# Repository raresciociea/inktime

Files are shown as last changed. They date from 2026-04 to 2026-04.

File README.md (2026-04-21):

# InkTime — Open Source E-Paper Smartwatch

> Cheap, open-source smartwatch built around the Nordic nRF52840 SoC and an e-paper display.

---

## Block Diagram

```text
                          ┌─────────────────────────────────────────────┐
                          │              nRF52840 (U$1)                  │
                          │                                              │
         ┌────────────┐   │  SPI (P0.02/P0.03/P0.05/P0.15/P0.16/P0.17) │
         │  E-Paper   │◄──┤  EPD power ctrl (P1.01)                    │
         │  Display   │   │                                              │
         │  (J2 FPC)  │   │  I2C (P0.06 SDA / P0.07 SCL)               │
         └────────────┘   │   ├─► BQ25180  (IC1)  Battery Charger       │
                          │   ├─► BMA423   (IC2)  Accelerometer/IMU     │
         ┌────────────┐   │   ├─► DRV2605  (IC3)  Haptic Driver         │
         │  Battery   │──►│   └─► MAX17048 (U1)   Fuel Gauge            │
         │  (LiPo)    │   │                                              │
         └────────────┘   │  GPIO                                        │
                          │   ├─► HAPTIC_EN  (P0.12)                    │
         ┌────────────┐   │   ├─► IMU_INT1   (P0.08)                    │
         │  Buttons   │──►│   ├─► IMU_INT2   (P1.08)                    │
         │  UP/ENT/DN │   │   ├─► PMIC_INT   (P0.11)                    │
         └────────────┘   │   ├─► SW_UP      (P0.13)                    │
                          │   ├─► SW_ENT     (P0.14)                    │
         ┌────────────┐   │   └─► SW_DN      (P1.02)                    │
         │ RT6160AWSC │◄──┤  I2C (shared bus)                           │
         │ Buck-Boost │   │                                              │
         │   (IC9)    │   │  SWD debug (SWDIO / SWDCLK / SWO)          │
         └────────────┘   │  32MHz XTAL (X1)  /  32.768kHz XTAL (X2)  │
                          │  2.4GHz Antenna (ANT1)                      │
         ┌────────────┐   └─────────────────────────────────────────────┘
         │  USB-C     │
         │  (J3)      │──► BQ25180 (charging)
         └────────────┘──► USBLC6-2SC6Y (ESD protection, D1)
```

---

## Bill of Materials (BOM)

| Ref | Qty | Component | Description | Package | JLC Parts Link | Datasheet |
|-----|-----|---|---|---|---|---|
| U$1 | 1 | nRF52840-QIAA | Main MCU — BLE 5.0 + ARM Cortex-M4F | AQFN-73 (7×7mm) | [JLC C190794](https://jlcpcb.com/partdetail/NordicSemiconductor-nRF52840_QIAA/C190794) | [Datasheet](https://infocenter.nordicsemi.com/pdf/nRF52840_PS_v1.5.pdf) |
| IC1 | 1 | BQ25180YBGR | 1-cell LiPo charger, I2C, 1A | 8-DSBGA (1.6×1.1mm) | [JLC Parts Search](https://jlcpcb.com/parts/componentSearch?searchTxt=BQ25180) | [Datasheet](https://www.ti.com/lit/ds/symlink/bq25180.pdf) |
| IC2 | 1 | BMA423 | Triaxial accelerometer + step counter, I2C/SPI | LGA-12 (2×2mm) | [JLC Parts Search](https://jlcpcb.com/parts/componentSearch?searchTxt=BMA423) | [Datasheet](https://www.bosch-sensortec.com/media/boschsensortec/downloads/datasheets/bst-bma423-ds000.pdf) |
| IC3 | 1 | DRV2605YZFR | Haptic driver for ERM/LRA motors, I2C | 9-BGA (1.44×1.44mm) | [JLC Parts Search](https://jlcpcb.com/parts/componentSearch?searchTxt=DRV2605YZFR) | [Datasheet](https://www.ti.com/lit/ds/symlink/drv2605.pdf) |
| U1 | 1 | MAX17048G+T10 | 1-cell fuel gauge, ModelGauge, I2C | TDFN-8 (2×2mm) | [JLC Parts Search](https://jlcpcb.com/parts/componentSearch?searchTxt=MAX17048G) | [Datasheet](https://datasheets.maximintegrated.com/en/ds/MAX17048-MAX17049.pdf) |
| IC9 | 1 | RT6160AWSC | Buck-boost DC/DC regulator, I2C | 15-WL-CSP (1.4×2.3mm) | [JLC Parts Search](https://jlcpcb.com/parts/componentSearch?searchTxt=RT6160AWSC) | [Datasheet](https://www.richtek.com/assets/product_file/RT6160A/DS6160A-00.pdf) |
| ANT1 | 1 | 2450AT18B100E | 2.45 GHz chip antenna | 3216 SMD | [JLC Parts Search](https://jlcpcb.com/parts/componentSearch?searchTxt=2450AT18B100E) | [Datasheet](https://www.johansontechnology.com/datasheets/2450AT18B100E.pdf) |
| J2 | 1 | Molex 503480-2400 | 0.5mm FPC connector, 24-pin, right-angle | SMD | [JLC Parts Search](https://jlcpcb.com/parts/componentSearch?searchTxt=503480-2400) | [Datasheet](https://www.molex.com/en-us/products/part-detail/5034802400) |
| J3 | 1 | KH-TYPE-C-16P | USB-C 16-pin receptacle | SMD | [JLC C2765186](https://jlcpcb.com/partdetail/Kinghelm-KH_TYPE_C_16P/C2765186) | [Datasheet](https://www.kinghelm.net/product/kh-type-c-16p.html) |
| J1 | 1 | TC2030-IDC | Tag-Connect 6-pin SWD debug connector | PTH | [Tag-Connect (External)](https://www.tag-connect.com/product/tc2030-idc) | [Datasheet](https://www.tag-connect.com/wp-content/uploads/bsk-pdf-manager/TC2030-IDC_1.pdf) |
| X1 | 1 | 32 MHz Crystal | Main RF crystal | 2016 SMD | JLC Parts | Nordic ref design |
| X2 | 1 | 32.768 kHz Crystal | RTC crystal | 3215 SMD | JLC Parts | Nordic ref design |
| L1 | 1 | Wurth 744043680 (68 µH) | EPD boost inductor | 4828 SMD | [JLC C408334](https://jlcpcb.com/partdetail/WurthElektronik-744043680/C408334) | [Datasheet](https://www.we-online.com/catalog/datasheet/744043680.pdf) |
| L2 | 1 | 10 µH inductor | DC-DC inductor for nRF DCC pin | 0201 | JLC Parts | — |
| L3 | 1 | 15 nH inductor | RF impedance matching network | 0201 | JLC Parts | — |
| L7 | 1 | FTC252012SR47MBCA (0.47 µH) | Buck-boost inductor | 2016 SMD | [JLC C5832368](https://jlcpcb.com/partdetail/6763488-FTC252012SR47MBCA/C5832368) | [Datasheet](https://product.tdk.com/en/search/inductor/inductor/smd/info?part_no=FTC252012SR47MBCA) |
| D1 | 1 | USBLC6-2SC6Y | USB ESD protection TVS diode array | SOT-23-6 | JLC Parts | [Datasheet](https://www.st.com/resource/en/datasheet/usblc6-2sc6y.pdf) |
| D2, D4, D5 | 3 | MBR0530 | Schottky diode 30V/0.5A | SOD-123 | JLC Parts | [Datasheet](https://www.onsemi.com/pdf/datasheet/mbr0530t1-d.pdf) |
| Q1 | 1 | P-channel MOSFET | EPD 3.3V power switch | SOT-23 | JLC Parts | — |
| Q3 | 1 | SI1308EDL-T1-GE3 | N-channel MOSFET 30V/1.5A, EPD gate driver | SC-70 | JLC Parts | [Datasheet](https://www.vishay.com/docs/63401/si1308edl.pdf) |
| SW_UP, SW_ENT, SW_DN | 3 | EVP-AKE31A | Tactile push button, SMD | SMD | JLC Parts | [Datasheet](https://industrial.panasonic.com/ww/products/pt/light-touch-switches/models/EVPAKE31A) |
| R1–R18, various | ~20 | Resistors | Various values (10K, 5K1, 3K3, 7.68K, 2.2Ω, 0.47Ω) | 0201 | JLC Parts | — |
| C1–C43, EPD_Cx | ~60 | Capacitors | 1pF – 22µF decoupling/filtering | 0201 (≤100nF), 0402 (>100nF) | JLC Parts | — |
| TP_* | 14 | Test pads | GND, 3V3, VBAT, SDA, SCL, SWDIO, SWDCLK, SWO, RESET, etc. | TP20R | — | — |
| SJ1 | 1 | Solder jumper | Configuration jumper | — | — | — |

---

## Hardware Functionality

### Microcontroller — nRF52840
The nRF52840 is an ARM Cortex-M4F SoC from Nordic Semiconductor operating at 64 MHz with 1 MB Flash and 256 KB RAM. It integrates a Bluetooth 5.0 radio (BLE + 802.15.4), hardware AES/ECB/CCM/AAR, and a USB 2.0 full-speed controller.

Two crystals are required:
- **32 MHz** (X1) connected to XC1/XC2 pins — main clock for the RF subsystem.
- **32.768 kHz** (X2) connected to XL1/XL2 pins — low-power RTC clock for sleep mode timekeeping.

The DCC pin is filtered with a 10 µH inductor (L2) and decoupling capacitors as recommended in the Nordic hardware guidelines.

---

### E-Paper Display — SPI
The e-paper display connects via a **24-pin 0.5 mm FPC** connector (J2, Molex 503480-2400). It is driven over **SPI** with additional GPIO control lines.

The display power rail (EPD_3V3) is generated by a boost converter built around inductor L1 (68 µH) and switched by Q1 (P-channel MOSFET), controlled by the nRF pin P1.01. The EPD gate driver circuit uses Q3 (SI1308EDL N-MOSFET) and Schottky diodes D2/D4/D5 (MBR0530) to generate the positive/negative gate voltages required by the e-paper panel.

A capacitor bank (EPD_C1 through EPD_C12, all 1 µF/50 V, 0402) buffers the gate voltage generation transients. A type-selection resistor (R_TYPE_SEL, 2.2 Ω) sets the display panel type via J2 pin 6.

**Communication interface:** SPI (4-wire + DC + RST + BUSY)

---

### Battery Charger — BQ25180YBGR (IC1)
The BQ25180 is a compact single-cell Li-Ion/LiPo charger from Texas Instruments in an 8-pin DSBGA package. It is configured and monitored over **I2C**.

Key features used:
- Charge current set by R1 (10 kΩ on TS/MR pin).
- SYS output (VREG net) powers the RT6160 buck-boost regulator and other system rails.
- INT line (PMIC_INT) alerts the nRF on charge state changes.
- The battery connects directly to two test pads (TP_VBAT, TP_BAT_GND) without a JST connector to save space.

Decoupling: C24 (10 µF) and C23 (100 nF) on VREG; C39 (10 µF) on the SYS output.

---

### Fuel Gauge — MAX17048G+T10 (U1)
The MAX17048 is a 1-cell ModelGauge fuel gauge communicating over **I2C** (shared bus with BQ25180 and DRV2605). It directly measures battery voltage and estimates state-of-charge without a sense resistor. VBAT connects directly to the CELL pin.

---

### Buck-Boost Regulator — RT6160AWSC (IC9)
The RT6160A is a 15-pin WL-CSP I2C-programmable buck-boost DC/DC converter that generates a stable 3.3 V output (3V3 rail) from the variable battery voltage (3.0–4.2 V). It uses inductor L7 (0.47 µH). Input decoupling: C25 (22 µF) + C33 (22 µF). Output decoupling: C21 (4.7 µF) + C20 (4.7 µF).

The regulator is enabled by the BQ25180 SYS pin (VREG net) and configured over the shared I2C bus.

---

### Accelerometer / IMU — BMA423 (IC2)
The BMA423 is a Bosch 12-bit 3-axis accelerometer in a 2×2 mm LGA package with an integrated step counter, tilt, and activity recognition engine.

It communicates over **I2C** (CSB tied to VDD to select I2C mode). Two interrupt outputs (INT1 → P0.08, INT2 → P1.08) allow the nRF to wake from sleep on motion events. SDO pin sets the I2C address (pulled to GND via R3 → address 0x18).

Decoupling: C37 (1 µF) on VDDIO; C38 (1 µF) on VDD.

---

### Haptic Driver — DRV2605YZFR (IC3)
The DRV2605 drives an ERM or LRA vibration motor and includes an internal waveform library. It is controlled over **I2C** with an additional enable line (HAPTIC_EN → P0.12). The motor output pins are broken out to test pads TP_OP and TP_ON for debugging. A 100 nF decoupling capacitor (C34) is placed on VDD.

---

### USB Interface — USB-C (J3) + ESD (D1)
The USB-C connector (KH-TYPE-C-16P) carries VBUS for charging and USB D+/D- for the nRF's built-in USB 2.0 FS peripheral. CC1 and CC2 lines have 5.1 kΩ pull-down resistors (R1_USB, R2_USB) to signal a default USB power sink.

ESD protection is provided by USBLC6-2SC6Y (D1) on D+/D−. Bulk decoupling on VBUS: C42 (1500 pF) + C43 (1500 pF).

---

### Debug Interface — TC2030-IDC (J1)
A Tag-Connect TC2030-IDC footprint provides SWD (SWDIO, SWDCLK) + SWO + RESET access without needing a permanent through-hole connector. All signals are also available on labeled test pads.

---

### Push Buttons
Three Panasonic EVP-AKE31A tactile SMD buttons (SW_UP, SW_ENT, SW_DN) are connected with RC debounce filters (10 kΩ pull-up + 1 µF capacitor on each signal line).

---

### RF Section — 2.4 GHz Antenna
The Johanson 2450AT18B100E chip antenna is placed at the board edge with a PCB cutout underneath (no copper, no routing under the antenna area). The matching network consists of L3 (15 nH series) and shunt components (C3: 1 pF, C4: 1 pF, C9: 820 pF, C11: 100 pF) per the Nordic nRF52840 reference design for a chip antenna.

---

## nRF52840 Pin Assignment

| nRF52840 Pin | Net / Signal | Connected To | Interface |
|---|---|---|---|
| P0.00 / XL1 | XL1 | X2 pin 2 (32.768 kHz crystal) | LFXO |
| P0.01 / XL2 | XL2 | X2 pin 1 (32.768 kHz crystal) | LFXO |
| P0.02 / AIN0 | SCK | J2 pin 13 → EPD display | SPI clock |
| P0.03 / AIN1 | MOSI | J2 pin 14 → EPD display | SPI MOSI |
| P0.05 / AIN3 | EPD_CS | J2 pin 12 → EPD chip select | SPI CS |
| P0.06 | SDA | IC1 (BQ25180), IC2 (BMA423), IC3 (DRV2605), U1 (MAX17048) | I2C data |
| P0.07 | SCL | IC1 (BQ25180), IC2 (BMA423), IC3 (DRV2605), U1 (MAX17048) | I2C clock |
| P0.08 | IMU_INT1 | IC2 (BMA423) INT1 | GPIO input |
| P0.11 | PMIC_INT | IC1 (BQ25180) !INT | GPIO input |
| P0.12 | HAPTIC_EN | IC3 (DRV2605) EN | GPIO output |
| P0.13 | SW_UP | SW_UP button | GPIO input |
| P0.14 | SW_ENT | SW_ENT button | GPIO input |
| P0.15 | EPD_DC | J2 pin 11 → EPD data/command | GPIO output |
| P0.16 | EPD_RST | J2 pin 10 → EPD reset | GPIO output |
| P0.17 | EPD_BUSY | J2 pin 9 → EPD busy flag | GPIO input |
| P0.18 / RESET | RESET | J1 pin 6, TP_RESET | System reset |
| P1.00 | SWO | J1, TP_SWO | SWD trace output |
| P1.01 | EPD power ctrl | Q1 gate via R_PWR_EPD | GPIO output (EPD rail enable) |
| P1.02 | SW_DN | SW_DN button | GPIO input |
| P1.08 | IMU_INT2 | IC2 (BMA423) INT2 | GPIO input |
| SWDCLK | SWDCLK | J1 pin 4, TP_SWDCLK | SWD debug |
| SWDIO | SWDIO | J1 pin 2, TP_SWDIO | SWD debug |
| DCC | DC/DC | L2 (10 µH) | Internal DC/DC choke |
| XC1 / XC2 | RF crystal | X1 (32 MHz) | HFXO |
| ANT | RF | L3 → ANT1 (2450AT18B100E) | 2.4 GHz RF |
| VDD | 3V3 | RT6160AWSC output (3.3 V) | Power |
| VDDH | 3V3 | Same 3.3 V rail | Power (high-voltage I/O) |
| DEC1–DEC6, DEC3V3 | Decoupling | Various 100 nF / 12 pF caps | Power decoupling |

> **Pin selection rationale:**
> - **P0.02/P0.03** were chosen for SCK/MOSI because they are fully flexible GPIO with no alternate function conflicts. The nRF52840 SPI master (SPIM) can be mapped to any GPIO.
> - **P0.06/P0.07** are used for I2C because they sit close to the BQ25180 and BMA423 physical placement area on the PCB, minimising trace length for the 400 kHz Fast-mode I2C bus.
> - **P0.00/P0.01** are the dedicated crystal pins for the 32.768 kHz LFXO and cannot be repurposed.
> - Buttons (P0.13, P0.14, P1.02) have hardware RC debounce circuits so any GPIO works; these were chosen as free pins after all peripherals were assigned.
> - **P1.01** drives the EPD power MOSFET through a resistor divider — any output-capable GPIO suffices.

---

## Power Budget (Estimated)

| Mode | nRF52840 | EPD refresh | BMA423 | DRV2605 | Total (est.) |
|---|---|---|---|---|---|
| Active (BLE advertising) | ~15 mA | 0 mA | 0.13 mA | 0 mA | ~15 mA |
| EPD refresh | 3 mA | ~30 mA peak | 0.13 mA | 0 mA | ~33 mA |
| Haptic feedback | 5 mA | 0 mA | 0 mA | ~60 mA | ~65 mA |
| Deep sleep (System OFF) | 2.5 µA | 0 mA | 0 µA | 0 µA | ~3 µA |

With a 180 mAh LiPo battery and a typical duty cycle (BLE advertising every 1 s, time display refreshed once per minute), estimated battery life is **5–7 days**.

---

## Test Pads

All test pads are clearly marked in the silkscreen layer with the signal name:

| Pad | Signal |
|---|---|
| TP_3V3 / TP_3.3V | 3.3 V regulated rail |
| TP_VBAT | Raw battery voltage |
| TP_BAT_GND | Battery ground |
| TP_GND | System ground |
| TP_SDA | I2C data |
| TP_SCL | I2C clock |
| TP_SWDIO | SWD data |
| TP_SWDCLK | SWD clock |
| TP_SWO | SWD trace |
| TP_RESET | System reset |
| TP_ON / TP_OP | Haptic motor − / + |
| TP_VREG | BQ25180 SYS output |

---

## Design Notes & Decisions

- **PCB thickness is 1 mm** (not standard 1.6 mm) to fit within the mechanical constraints of the case.
- **All components are placed on the TOP layer only**, as required by the project specification.
- **Ground planes** are present on both TOP and BOTTOM layers; via stitching is applied between the two planes, especially around the RF section.
- **No copper or routing under the antenna** (2450AT18B100E, ANT1): the PCB is cut out under the antenna footprint and the area is excluded from the ground plane pour.
- **Decoupling capacitors** (100 nF, 0201) are placed as close as possible to each IC power pin.
- **Power traces** (VCC, 3V3, VBAT) are routed at **0.3 mm** width; data signals at minimum **0.15 mm**. Traces under BGA pads are reduced as required by the via fanout geometry.
- **No right-angle trace bends** — all routing uses 45° chamfers.
- **Battery connection** is made directly to TP_VBAT and TP_BAT_GND solder pads (no JST connector) to maximise vertical clearance inside the case.
- **ERC errors:** The "Only INPUT pins on NET ID" warning is accepted per project guidelines.
- **Dimension errors** caused by the three button cutouts and USB-C aperture in the board outline are accepted per project guidelines.

---

## Repository Structure

```text
InkTime/
├── Hardware/
│   ├── InkTime.sch           # Eagle schematic
│   ├── InkTime.brd           # Eagle board file
│   └── InkTime.pdf           # Exported schematic pdf
├── Manufacturing/
│   ├── Gerbers.zip           # Gerber + drill files
│   ├── InkTime_BOM.bom       # Bill of Materials
│   └── Inktime_PnP.cpl       # Pick & Place file
├── Mechanical/
│   ├── InkTime.stp           # 3D CAD full assembly
│   └── InkTime_Exploded.stp  # 3D CAD exploded view
├── Images/
│   └── (PCB renders, 3D renders)
├── LICENSE
└── README.md
```

---

## License

This project is released under the **Apache License 2.0**. See [LICENSE](LICENSE) for details.

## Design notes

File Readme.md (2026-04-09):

# InkTime — Open Source E-Paper Smartwatch

> Cheap, open-source smartwatch built around the Nordic nRF52840 SoC and an e-paper display.

---

## Block Diagram

```
                          ┌─────────────────────────────────────────────┐
                          │              nRF52840 (U$1)                  │
                          │                                              │
         ┌────────────┐   │  SPI (P0.02/P0.03/P0.05/P0.15/P0.16/P0.17) │
         │  E-Paper   │◄──┤  EPD power ctrl (P1.01)                    │
         │  Display   │   │                                              │
         │  (J2 FPC)  │   │  I2C (P0.06 SDA / P0.07 SCL)               │
         └────────────┘   │   ├─► BQ25180  (IC1)  Battery Charger       │
                          │   ├─► BMA423   (IC2)  Accelerometer/IMU     │
         ┌────────────┐   │   ├─► DRV2605  (IC3)  Haptic Driver         │
         │  Battery   │──►│   └─► MAX17048 (U1)   Fuel Gauge            │
         │  (LiPo)    │   │                                              │
         └────────────┘   │  GPIO                                        │
                          │   ├─► HAPTIC_EN  (P0.12)                    │
         ┌────────────┐   │   ├─► IMU_INT1   (P0.08)                    │
         │  Buttons   │──►│   ├─► IMU_INT2   (P1.08)                    │
         │  UP/ENT/DN │   │   ├─► PMIC_INT   (P0.11)                    │
         └────────────┘   │   ├─► SW_UP      (P0.13)                    │
                          │   ├─► SW_ENT     (P0.14)                    │
         ┌────────────┐   │   └─► SW_DN      (P1.02)                    │
         │ RT6160AWSC │◄──┤  I2C (shared bus)                           │
         │ Buck-Boost │   │                                              │
         │   (IC9)    │   │  SWD debug (SWDIO / SWDCLK / SWO)          │
         └────────────┘   │  32MHz XTAL (X1)  /  32.768kHz XTAL (X2)  │
                          │  2.4GHz Antenna (ANT1)                      │
         ┌────────────┐   └─────────────────────────────────────────────┘
         │  USB-C     │
         │  (J3)      │──► BQ25180 (charging)
         └────────────┘──► USBLC6-2SC6Y (ESD protection, D1)
```

---

## Bill of Materials (BOM)

| Ref | Qty | Component | Description | Package | JLCPCB / Procurement | Datasheet |
|-----|-----|---|---|---|---|---|
| U$1 | 1 | nRF52840-QIAA | Main MCU — BLE 5.0 + ARM Cortex-M4F | AQFN-73 (7×7mm) | [JLCPCB](https://jlcpcb.com/partdetail/NordicSemiconductor-nRF52840_QIAA/C190794) | [Datasheet](https://infocenter.nordicsemi.com/pdf/nRF52840_PS_v1.5.pdf) |
| IC1 | 1 | BQ25180YBGR | 1-cell LiPo charger, I2C, 1A | 8-DSBGA (1.6×1.1mm) | [Mouser](https://www.mouser.co.uk/ProductDetail/Texas-Instruments/BQ25180YBGR) | [Datasheet](https://www.ti.com/lit/ds/symlink/bq25180.pdf) |
| IC2 | 1 | BMA423 | Triaxial accelerometer + step counter, I2C/SPI | LGA-12 (2×2mm) | [Mouser](https://www.mouser.co.uk/ProductDetail/Bosch-Sensortec/BMA423) | [Datasheet](https://www.bosch-sensortec.com/media/boschsensortec/downloads/datasheets/bst-bma423-ds000.pdf) |
| IC3 | 1 | DRV2605YZFR | Haptic driver for ERM/LRA motors, I2C | 9-BGA (1.44×1.44mm) | [Arrow](https://www.arrow.com/en/products/drv2605yzfr/texas-instruments) | [Datasheet](https://www.ti.com/lit/ds/symlink/drv2605.pdf) |
| U1 | 1 | MAX17048G+T10 | 1-cell fuel gauge, ModelGauge, I2C | TDFN-8 (2×2mm) | [SnapEDA/Mouser](https://www.snapeda.com/parts/MAX17048G+T10/Analog+Devices/view-part/) | [Datasheet](https://datasheets.maximintegrated.com/en/ds/MAX17048-MAX17049.pdf) |
| IC9 | 1 | RT6160AWSC | Buck-boost DC/DC regulator, I2C | 15-WL-CSP (1.4×2.3mm) | [Mouser](https://www.mouser.co.uk/ProductDetail/Richtek/RT6160AWSC) | [Datasheet](https://www.richtek.com/assets/product_file/RT6160A/DS6160A-00.pdf) |
| ANT1 | 1 | 2450AT18B100E | 2.45 GHz chip antenna | 3216 SMD | [Mouser](https://www.mouser.co.uk/ProductDetail/Johanson-Technology/2450AT18B100E) | [Datasheet](https://www.johansontechnology.com/datasheets/2450AT18B100E.pdf) |
| J2 | 1 | Molex 503480-2400 | 0.5mm FPC connector, 24-pin, right-angle | SMD | [Mouser](https://www.mouser.co.uk/ProductDetail/Molex/503480-2400) | [Datasheet](https://www.molex.com/en-us/products/part-detail/5034802400) |
| J3 | 1 | KH-TYPE-C-16P | USB-C 16-pin receptacle | SMD | [JLCPCB](https://jlcpcb.com/partdetail/Kinghelm-KH_TYPE_C_16P/C2765186) | [Datasheet](https://www.kinghelm.net/product/kh-type-c-16p.html) |
| J1 | 1 | TC2030-IDC | Tag-Connect 6-pin SWD debug connector | PTH | [Tag-Connect](https://www.tag-connect.com/product/tc2030-idc) | [Datasheet](https://www.tag-connect.com/wp-content/uploads/bsk-pdf-manager/TC2030-IDC_1.pdf) |
| X1 | 1 | 32 MHz Crystal | Main RF crystal | 2016 SMD | JLCPCB parts | Nordic ref design |
| X2 | 1 | 32.768 kHz Crystal | RTC crystal | 3215 SMD | JLCPCB parts | Nordic ref design |
| L1 | 1 | Wurth 744043680 (68 µH) | EPD boost inductor | 4828 SMD | [JLCPCB](https://jlcpcb.com/partdetail/WurthElektronik-744043680/C408334) | [Datasheet](https://www.we-online.com/catalog/datasheet/744043680.pdf) |
| L2 | 1 | 10 µH inductor | DC-DC inductor for nRF DCC pin | 0201 | JLCPCB parts | — |
| L3 | 1 | 15 nH inductor | RF impedance matching network | 0201 | JLCPCB parts | — |
| L7 | 1 | FTC252012SR47MBCA (0.47 µH) | Buck-boost inductor | 2016 SMD | [JLCPCB](https://jlcpcb.com/partdetail/6763488-FTC252012SR47MBCA/C5832368) | [Datasheet](https://product.tdk.com/en/search/inductor/inductor/smd/info?part_no=FTC252012SR47MBCA) |
| D1 | 1 | USBLC6-2SC6Y | USB ESD protection TVS diode array | SOT-23-6 | JLCPCB parts | [Datasheet](https://www.st.com/resource/en/datasheet/usblc6-2sc6y.pdf) |
| D2, D4, D5 | 3 | MBR0530 | Schottky diode 30V/0.5A | SOD-123 | JLCPCB parts | [Datasheet](https://www.onsemi.com/pdf/datasheet/mbr0530t1-d.pdf) |
| Q1 | 1 | P-channel MOSFET | EPD 3.3V power switch | SOT-23 | JLCPCB parts | — |
| Q3 | 1 | SI1308EDL-T1-GE3 | N-channel MOSFET 30V/1.5A, EPD gate driver | SC-70 | JLCPCB parts | [Datasheet](https://www.vishay.com/docs/63401/si1308edl.pdf) |
| SW_UP, SW_ENT, SW_DN | 3 | EVP-AKE31A | Tactile push button, SMD | SMD | JLCPCB parts | [Datasheet](https://industrial.panasonic.com/ww/products/pt/light-touch-switches/models/EVPAKE31A) |
| R1–R18, various | ~20 | Resistors | Various values (10K, 5K1, 3K3, 7.68K, 2.2Ω, 0.47Ω) | 0201 | JLCPCB parts | — |
| C1–C43, EPD_Cx | ~60 | Capacitors | 1pF – 22µF decoupling/filtering | 0201 (≤100nF), 0402 (>100nF) | JLCPCB parts | — |
| TP_* | 14 | Test pads | GND, 3V3, VBAT, SDA, SCL, SWDIO, SWDCLK, SWO, RESET, etc. | TP20R | — | — |
| SJ1 | 1 | Solder jumper | Configuration jumper | — | — | — |

---

## Hardware Functionality

### Microcontroller — nRF52840

The nRF52840 is an ARM Cortex-M4F SoC from Nordic Semiconductor operating at 64 MHz with 1 MB Flash and 256 KB RAM. It integrates a Bluetooth 5.0 radio (BLE + 802.15.4), hardware AES/ECB/CCM/AAR, and a USB 2.0 full-speed controller.

Two crystals are required:
- **32 MHz** (X1) connected to XC1/XC2 pins — main clock for the RF subsystem.
- **32.768 kHz** (X2) connected to XL1/XL2 pins — low-power RTC clock for sleep mode timekeeping.

The DCC pin is filtered with a 10 µH inductor (L2) and decoupling capacitors as recommended in the Nordic hardware guidelines.

---

### E-Paper Display — SPI

The e-paper display connects via a **24-pin 0.5 mm FPC** connector (J2, Molex 503480-2400). It is driven over **SPI** with additional GPIO control lines.

The display power rail (EPD_3V3) is generated by a boost converter built around inductor L1 (68 µH) and switched by Q1 (P-channel MOSFET), controlled by the nRF pin P1.01. The EPD gate driver circuit uses Q3 (SI1308EDL N-MOSFET) and Schottky diodes D2/D4/D5 (MBR0530) to generate the positive/negative gate voltages required by the e-paper panel.

A capacitor bank (EPD_C1 through EPD_C12, all 1 µF/50 V, 0402) buffers the gate voltage generation transients. A type-selection resistor (R_TYPE_SEL, 2.2 Ω) sets the display panel type via J2 pin 6.

**Communication interface:** SPI (4-wire + DC + RST + BUSY)

---

### Battery Charger — BQ25180YBGR (IC1)

The BQ25180 is a compact single-cell Li-Ion/LiPo charger from Texas Instruments in an 8-pin DSBGA package. It is configured and monitored over **I2C**.

Key features used:
- Charge current set by R1 (10 kΩ on TS/MR pin).
- SYS output (VREG net) powers the RT6160 buck-boost regulator and other system rails.
- INT line (PMIC_INT) alerts the nRF on charge state changes.
- The battery connects directly to two test pads (TP_VBAT, TP_BAT_GND) without a JST connector to save space.

Decoupling: C24 (10 µF) and C23 (100 nF) on VREG; C39 (10 µF) on the SYS output.

---

### Fuel Gauge — MAX17048G+T10 (U1)

The MAX17048 is a 1-cell ModelGauge fuel gauge communicating over **I2C** (shared bus with BQ25180 and DRV2605). It directly measures battery voltage and estimates state-of-charge without a sense resistor. VBAT connects directly to the CELL pin.

---

### Buck-Boost Regulator — RT6160AWSC (IC9)

The RT6160A is a 15-pin WL-CSP I2C-programmable buck-boost DC/DC converter that generates a stable 3.3 V output (3V3 rail) from the variable battery voltage (3.0–4.2 V). It uses inductor L7 (0.47 µH). Input decoupling: C25 (22 µF) + C33 (22 µF). Output decoupling: C21 (4.7 µF) + C20 (4.7 µF).

The regulator is enabled by the BQ25180 SYS pin (VREG net) and configured over the shared I2C bus.

---

### Accelerometer / IMU — BMA423 (IC2)

The BMA423 is a Bosch 12-bit 3-axis accelerometer in a 2×2 mm LGA package with an integrated step counter, tilt, and activity recognition engine.

It communicates over **I2C** (CSB tied to VDD to select I2C mode). Two interrupt outputs (INT1 → P0.08, INT2 → P1.08) allow the nRF to wake from sleep on motion events. SDO pin sets the I2C address (pulled to GND via R3 → address 0x18).

Decoupling: C37 (1 µF) on VDDIO; C38 (1 µF) on VDD.

---

### Haptic Driver — DRV2605YZFR (IC3)

The DRV2605 drives an ERM or LRA vibration motor and includes an internal waveform library. It is controlled over **I2C** with an additional enable line (HAPTIC_EN → P0.12). The motor output pins are broken out to test pads TP_OP and TP_ON for debugging. A 100 nF decoupling capacitor (C34) is placed on VDD.

---

### USB Interface — USB-C (J3) + ESD (D1)

The USB-C connector (KH-TYPE-C-16P) carries VBUS for charging and USB D+/D- for the nRF's built-in USB 2.0 FS peripheral. CC1 and CC2 lines have 5.1 kΩ pull-down resistors (R1_USB, R2_USB) to signal a default USB power sink.

ESD protection is provided by USBLC6-2SC6Y (D1) on D+/D−. Bulk decoupling on VBUS: C42 (1500 pF) + C43 (1500 pF).

---

### Debug Interface — TC2030-IDC (J1)

A Tag-Connect TC2030-IDC footprint provides SWD (SWDIO, SWDCLK) + SWO + RESET access without needing a permanent through-hole connector. All signals are also available on labeled test pads.

---

### Push Buttons

Three Panasonic EVP-AKE31A tactile SMD buttons (SW_UP, SW_ENT, SW_DN) are connected with RC debounce filters (10 kΩ pull-up + 1 µF capacitor on each signal line).

---

### RF Section — 2.4 GHz Antenna

The Johanson 2450AT18B100E chip antenna is placed at the board edge with a PCB cutout underneath (no copper, no routing under the antenna area). The matching network consists of L3 (15 nH series) and shunt components (C3: 1 pF, C4: 1 pF, C9: 820 pF, C11: 100 pF) per the Nordic nRF52840 reference design for a chip antenna.

---

## nRF52840 Pin Assignment

| nRF52840 Pin | Net / Signal | Connected To | Interface |
|---|---|---|---|
| P0.00 / XL1 | XL1 | X2 pin 2 (32.768 kHz crystal) | LFXO |
| P0.01 / XL2 | XL2 | X2 pin 1 (32.768 kHz crystal) | LFXO |
| P0.02 / AIN0 | SCK | J2 pin 13 → EPD display | SPI clock |
| P0.03 / AIN1 | MOSI | J2 pin 14 → EPD display | SPI MOSI |
| P0.05 / AIN3 | EPD_CS | J2 pin 12 → EPD chip select | SPI CS |
| P0.06 | SDA | IC1 (BQ25180), IC2 (BMA423), IC3 (DRV2605), U1 (MAX17048) | I2C data |
| P0.07 | SCL | IC1 (BQ25180), IC2 (BMA423), IC3 (DRV2605), U1 (MAX17048) | I2C clock |
| P0.08 | IMU_INT1 | IC2 (BMA423) INT1 | GPIO input |
| P0.11 | PMIC_INT | IC1 (BQ25180) !INT | GPIO input |
| P0.12 | HAPTIC_EN | IC3 (DRV2605) EN | GPIO output |
| P0.13 | SW_UP | SW_UP button | GPIO input |
| P0.14 | SW_ENT | SW_ENT button | GPIO input |
| P0.15 | EPD_DC | J2 pin 11 → EPD data/command | GPIO output |
| P0.16 | EPD_RST | J2 pin 10 → EPD reset | GPIO output |
| P0.17 | EPD_BUSY | J2 pin 9 → EPD busy flag | GPIO input |
| P0.18 / RESET | RESET | J1 pin 6, TP_RESET | System reset |
| P1.00 | SWO | J1, TP_SWO | SWD trace output |
| P1.01 | EPD power ctrl | Q1 gate via R_PWR_EPD | GPIO output (EPD rail enable) |
| P1.02 | SW_DN | SW_DN button | GPIO input |
| P1.08 | IMU_INT2 | IC2 (BMA423) INT2 | GPIO input |
| SWDCLK | SWDCLK | J1 pin 4, TP_SWDCLK | SWD debug |
| SWDIO | SWDIO | J1 pin 2, TP_SWDIO | SWD debug |
| DCC | DC/DC | L2 (10 µH) | Internal DC/DC choke |
| XC1 / XC2 | RF crystal | X1 (32 MHz) | HFXO |
| ANT | RF | L3 → ANT1 (2450AT18B100E) | 2.4 GHz RF |
| VDD | 3V3 | RT6160AWSC output (3.3 V) | Power |
| VDDH | 3V3 | Same 3.3 V rail | Power (high-voltage I/O) |
| DEC1–DEC6, DEC3V3 | Decoupling | Various 100 nF / 12 pF caps | Power decoupling |

> **Pin selection rationale:**
> - **P0.02/P0.03** were chosen for SCK/MOSI because they are fully flexible GPIO with no alternate function conflicts. The nRF52840 SPI master (SPIM) can be mapped to any GPIO.
> - **P0.06/P0.07** are used for I2C because they sit close to the BQ25180 and BMA423 physical placement area on the PCB, minimising trace length for the 400 kHz Fast-mode I2C bus.
> - **P0.00/P0.01** are the dedicated crystal pins for the 32.768 kHz LFXO and cannot be repurposed.
> - Buttons (P0.13, P0.14, P1.02) have hardware RC debounce circuits so any GPIO works; these were chosen as free pins after all peripherals were assigned.
> - **P1.01** drives the EPD power MOSFET through a resistor divider — any output-capable GPIO suffices.

---

## Power Budget (Estimated)

| Mode | nRF52840 | EPD refresh | BMA423 | DRV2605 | Total (est.) |
|---|---|---|---|---|---|
| Active (BLE advertising) | ~15 mA | 0 mA | 0.13 mA | 0 mA | ~15 mA |
| EPD refresh | 3 mA | ~30 mA peak | 0.13 mA | 0 mA | ~33 mA |
| Haptic feedback | 5 mA | 0 mA | 0 mA | ~60 mA | ~65 mA |
| Deep sleep (System OFF) | 2.5 µA | 0 mA | 0 µA | 0 µA | ~3 µA |

With a 180 mAh LiPo battery and a typical duty cycle (BLE advertising every 1 s, time display refreshed once per minute), estimated battery life is **5–7 days**.

---

## Test Pads

All test pads are clearly marked in the silkscreen layer with the signal name:

| Pad | Signal |
|---|---|
| TP_3V3 / TP_3.3V | 3.3 V regulated rail |
| TP_VBAT | Raw battery voltage |
| TP_BAT_GND | Battery ground |
| TP_GND | System ground |
| TP_SDA | I2C data |
| TP_SCL | I2C clock |
| TP_SWDIO | SWD data |
| TP_SWDCLK | SWD clock |
| TP_SWO | SWD trace |
| TP_RESET | System reset |
| TP_ON / TP_OP | Haptic motor − / + |
| TP_VREG | BQ25180 SYS output |

---

## Design Notes & Decisions

- **PCB thickness is 1 mm** (not standard 1.6 mm) to fit within the mechanical constraints of the case.
- **All components are placed on the TOP layer only**, as required by the project specification.
- **Ground planes** are present on both TOP and BOTTOM layers; via stitching is applied between the two planes, especially around the RF section.
- **No copper or routing under the antenna** (2450AT18B100E, ANT1): the PCB is cut out under the antenna footprint and the area is excluded from the ground plane pour.
- **Decoupling capacitors** (100 nF, 0201) are placed as close as possible to each IC power pin.
- **Power traces** (VCC, 3V3, VBAT) are routed at **0.3 mm** width; data signals at minimum **0.15 mm**. Traces under BGA pads are reduced as required by the via fanout geometry.
- **No right-angle trace bends** — all routing uses 45° chamfers.
- **Battery connection** is made directly to TP_VBAT and TP_BAT_GND solder pads (no JST connector) to maximise vertical clearance inside the case.
- **ERC errors:** The "Only INPUT pins on NET ID" warning is accepted per project guidelines.
- **Dimension errors** caused by the three button cutouts and USB-C aperture in the board outline are accepted per project guidelines.

---

## Repository Structure

```
InkTime/
├── Hardware/
│   ├── InkTime.sch          # Eagle schematic
│   └── InkTime.brd          # Eagle board file
├── Manufacturing/
│   ├── Gerbers.zip           # Gerber + drill files
│   ├── InkTime_BOM.bom       # Bill of Materials
│   └── Inktime_PnP.cpl       # Pick & Place file
├── Mechanical/
│   ├── InkTime.f3z           # Fusion 360 full assembly
│   └── InkTime_Exploded.f3z  # Fusion 360 exploded view
├── Images/
│   └── (PCB renders, 3D renders)
├── LICENSE
└── README.md
```

---

## License

This project is released under the **Apache License 2.0**. See [LICENSE](LICENSE) for details.

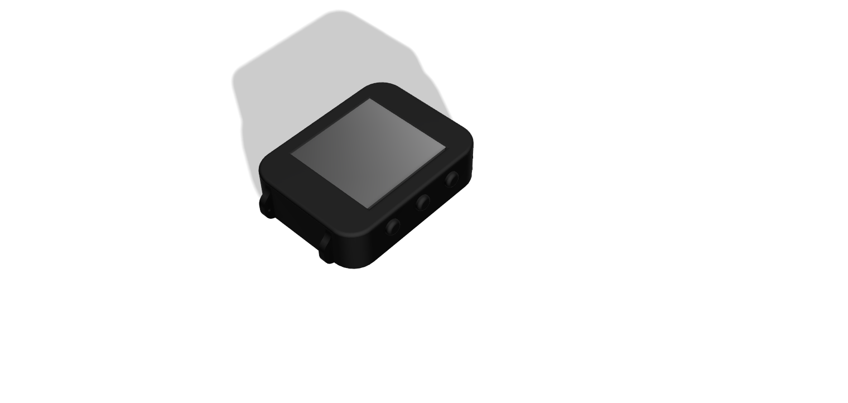
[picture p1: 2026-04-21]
Images/InkTime_Render.png

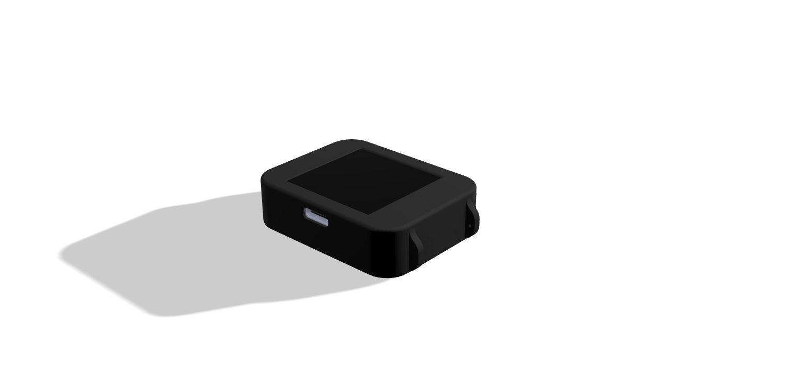
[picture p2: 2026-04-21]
Images/InkTime_Render_2.png

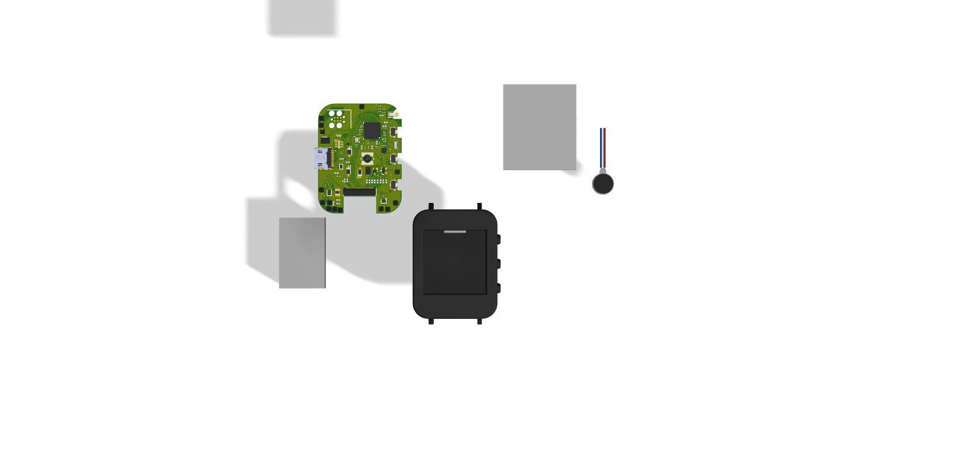
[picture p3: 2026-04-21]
Images/InkTime_Render_Exploded_2.png

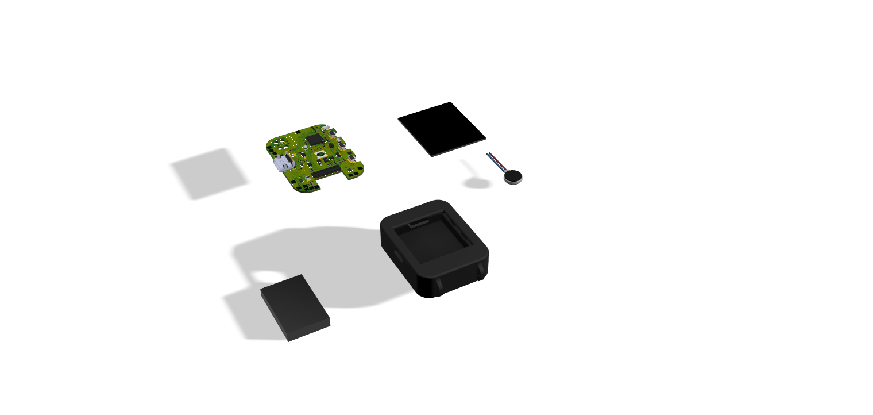
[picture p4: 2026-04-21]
Images/InkTime_Render_Exploded_3.png

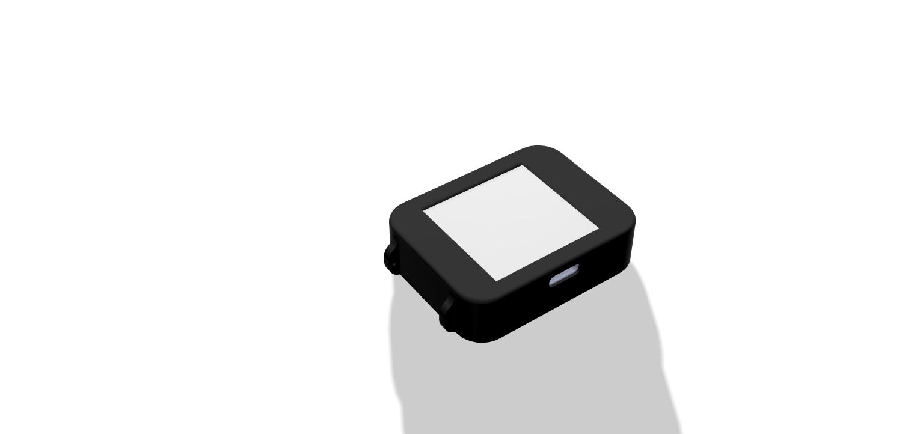
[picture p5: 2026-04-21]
Images/InkTime_Render_1.png

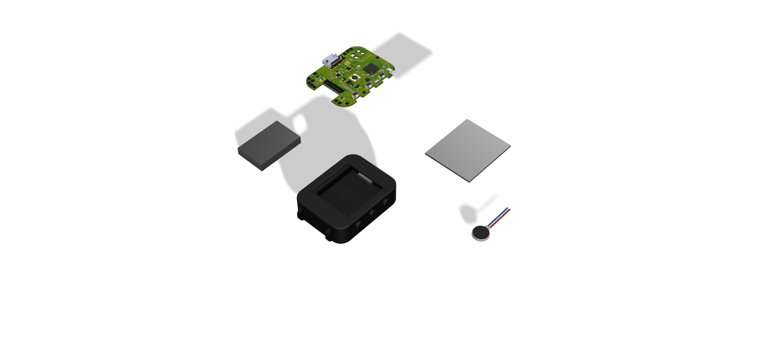
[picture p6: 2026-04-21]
Images/InkTime_Render_Exploded.png

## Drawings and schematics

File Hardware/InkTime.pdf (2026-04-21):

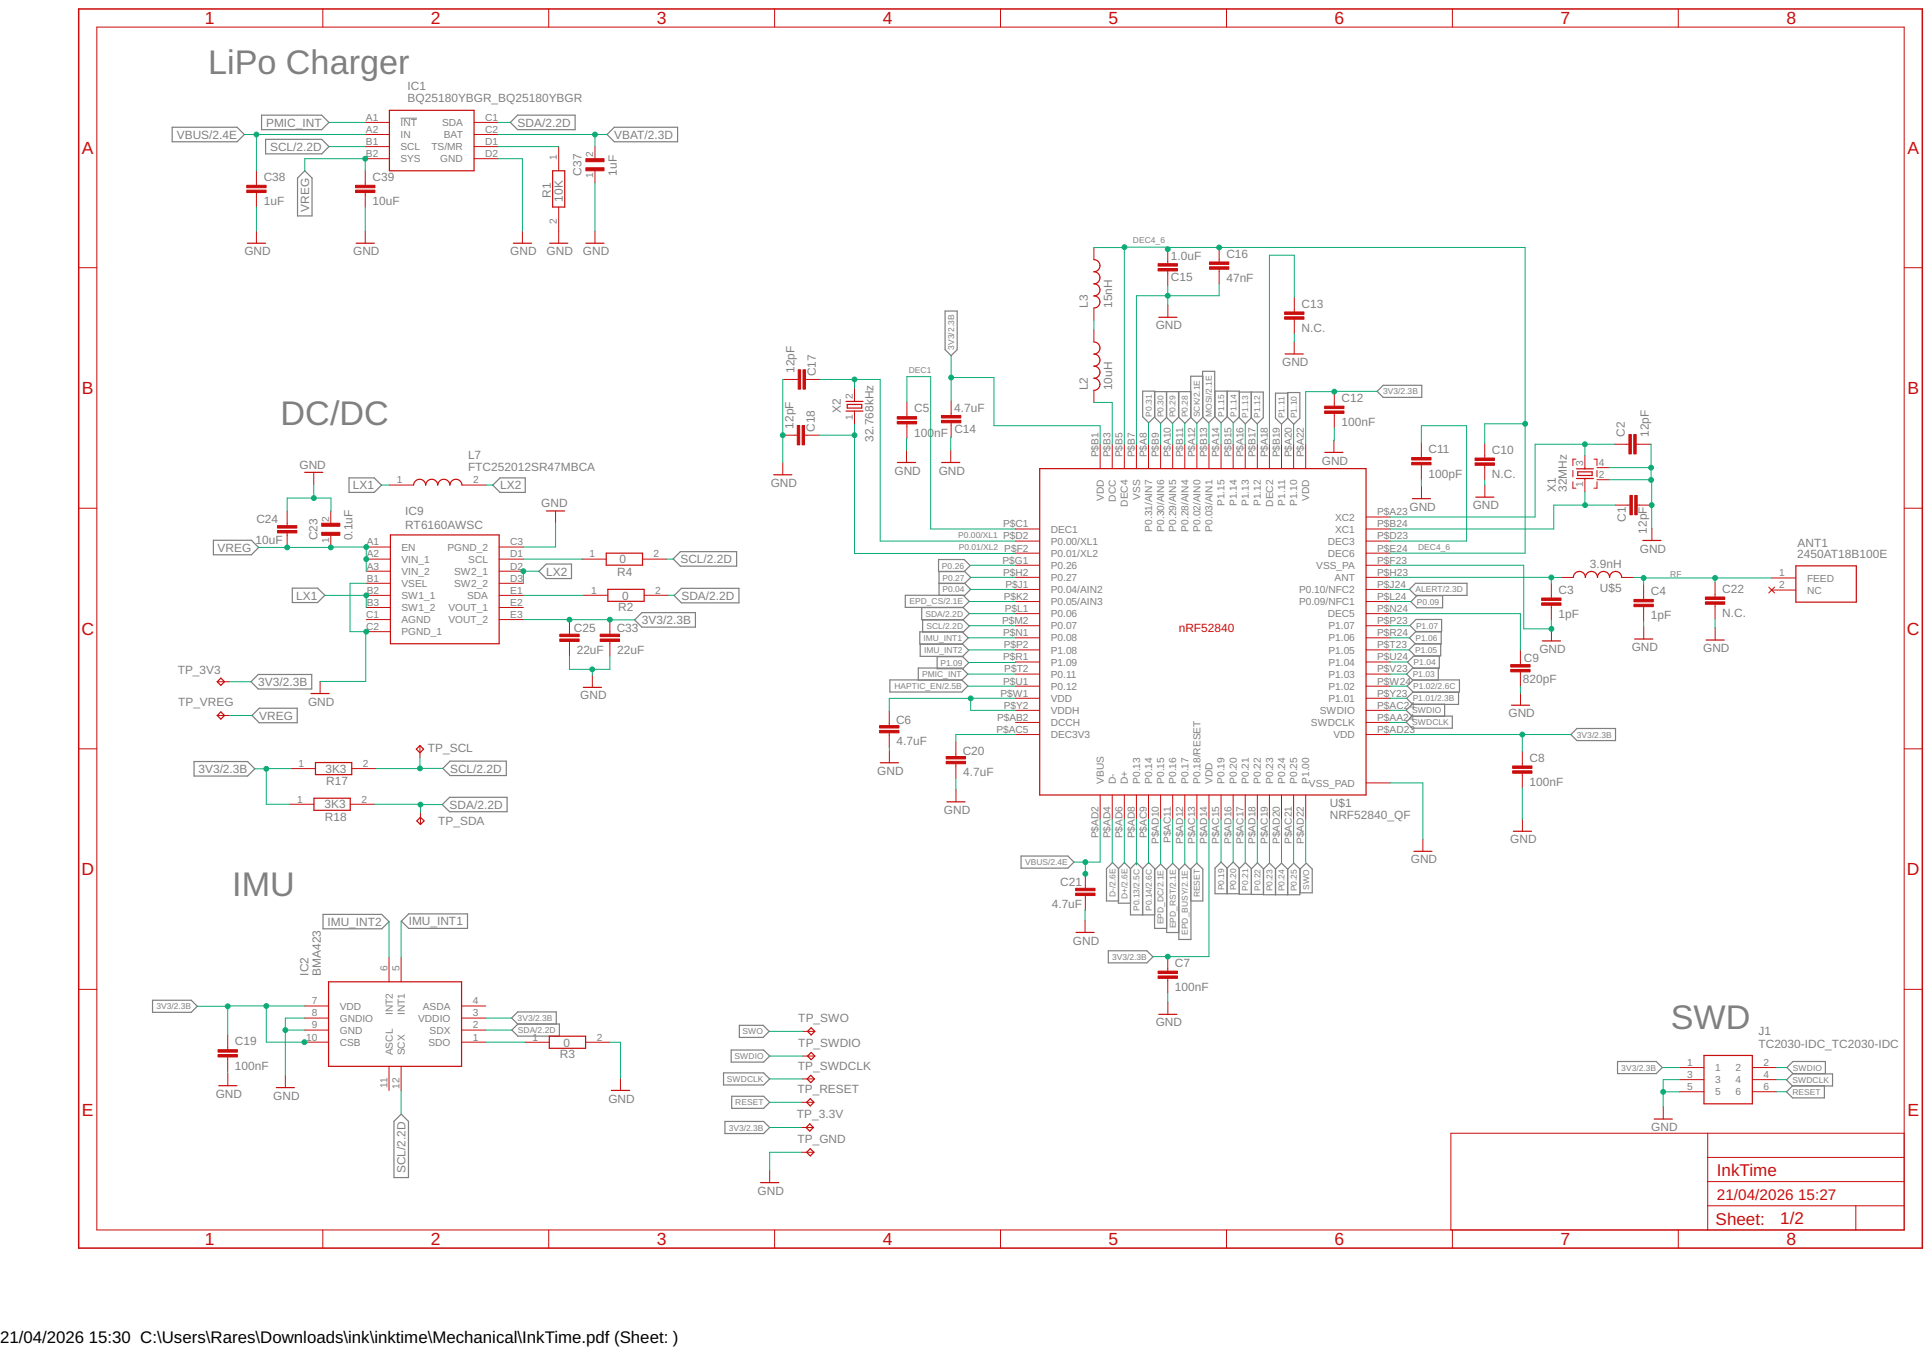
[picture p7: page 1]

21/04/2026 15:30 C:\Users\Rares\Downloads\ink\inktime\Mechanical\InkTime.pdf (Sheet: )

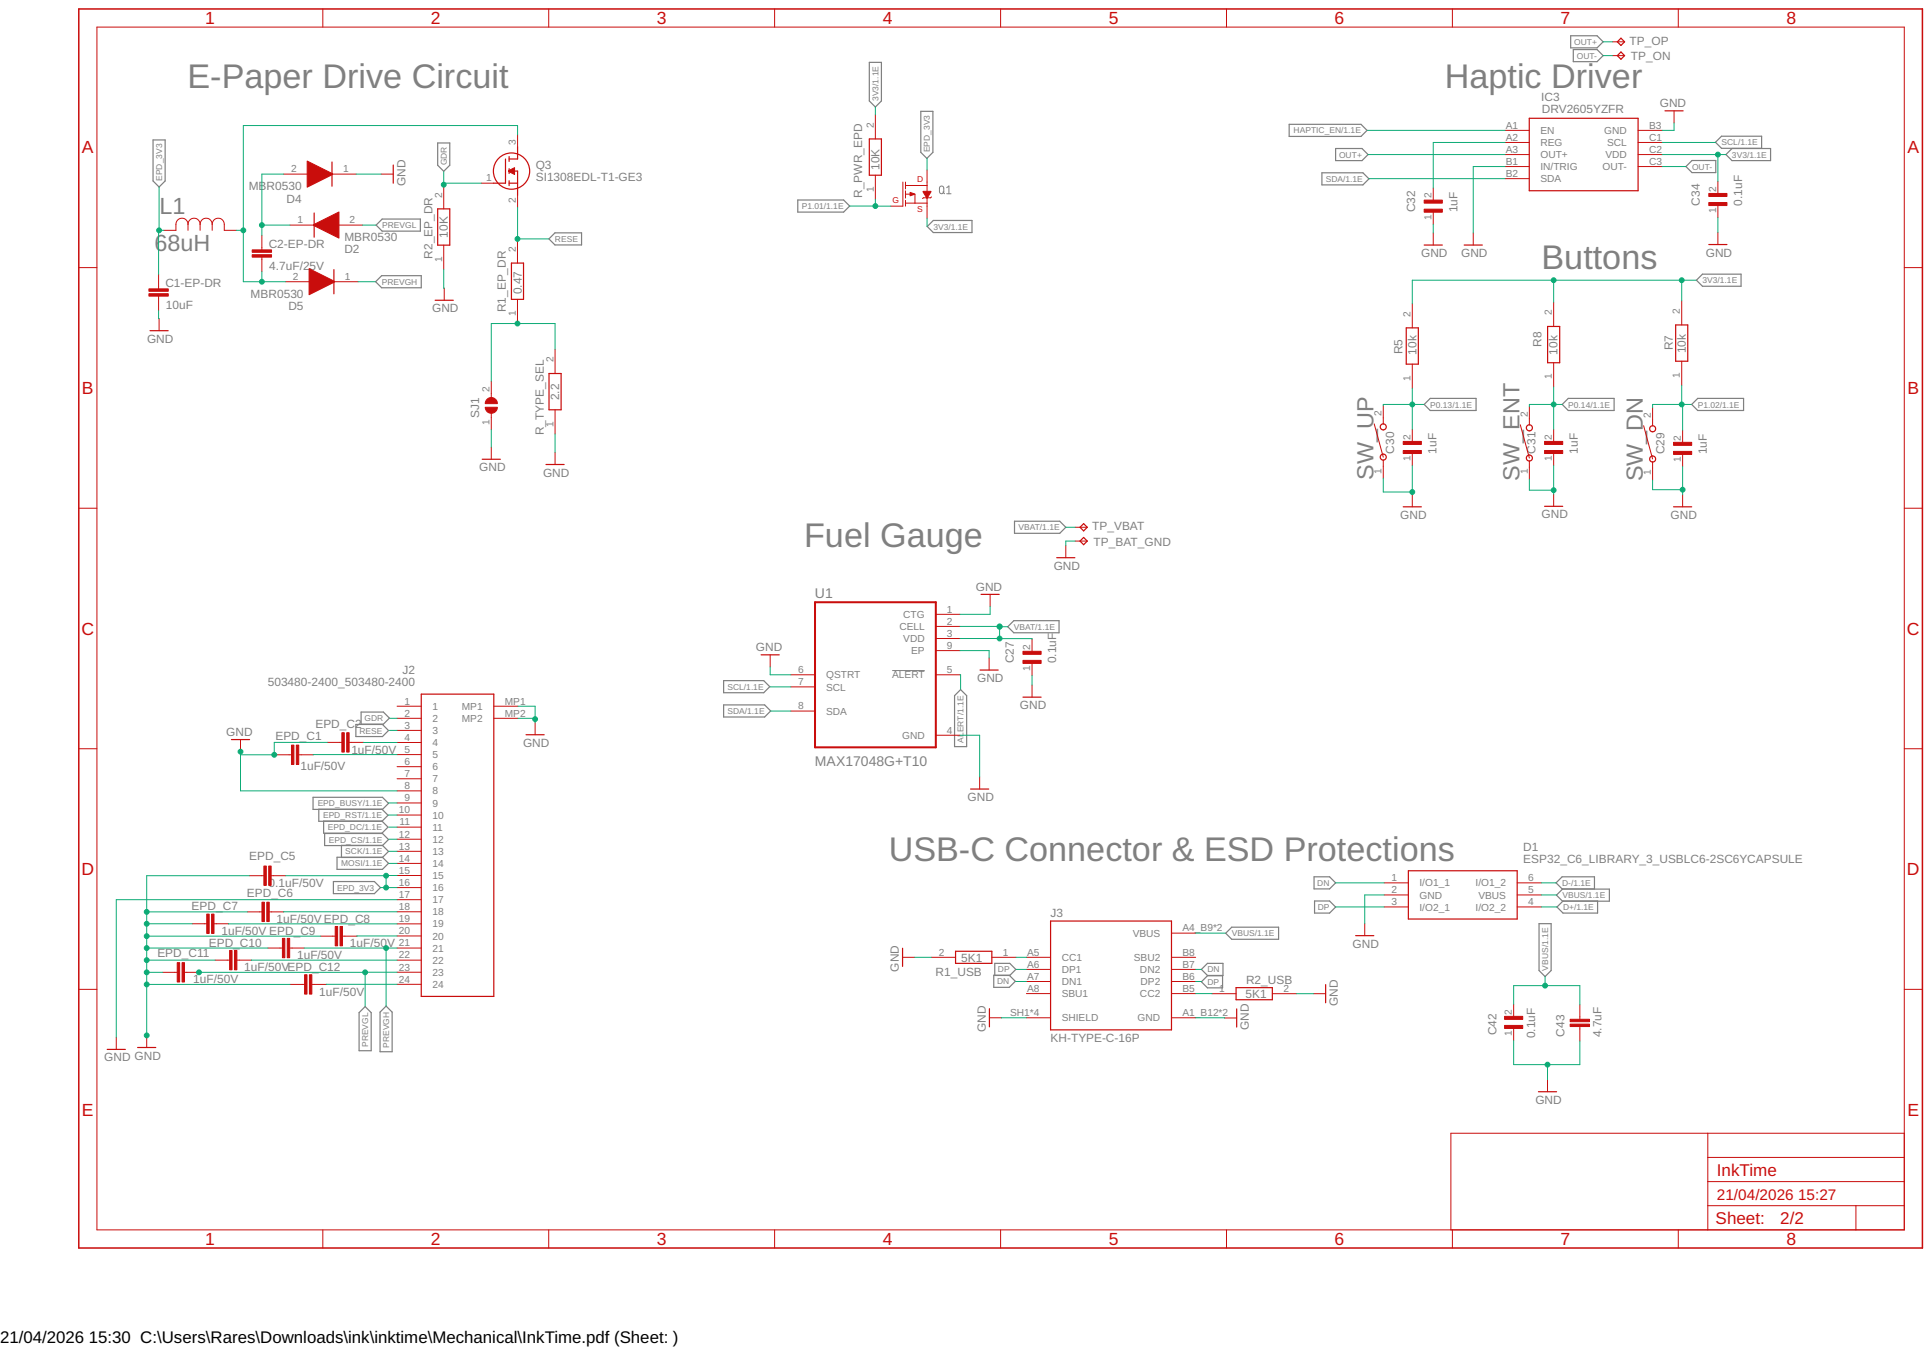
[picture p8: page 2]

GND

USB-C Connector & ESD Protections

21/04/2026 15:30 C:\Users\Rares\Downloads\ink\inktime\Mechanical\InkTime.pdf (Sheet: )

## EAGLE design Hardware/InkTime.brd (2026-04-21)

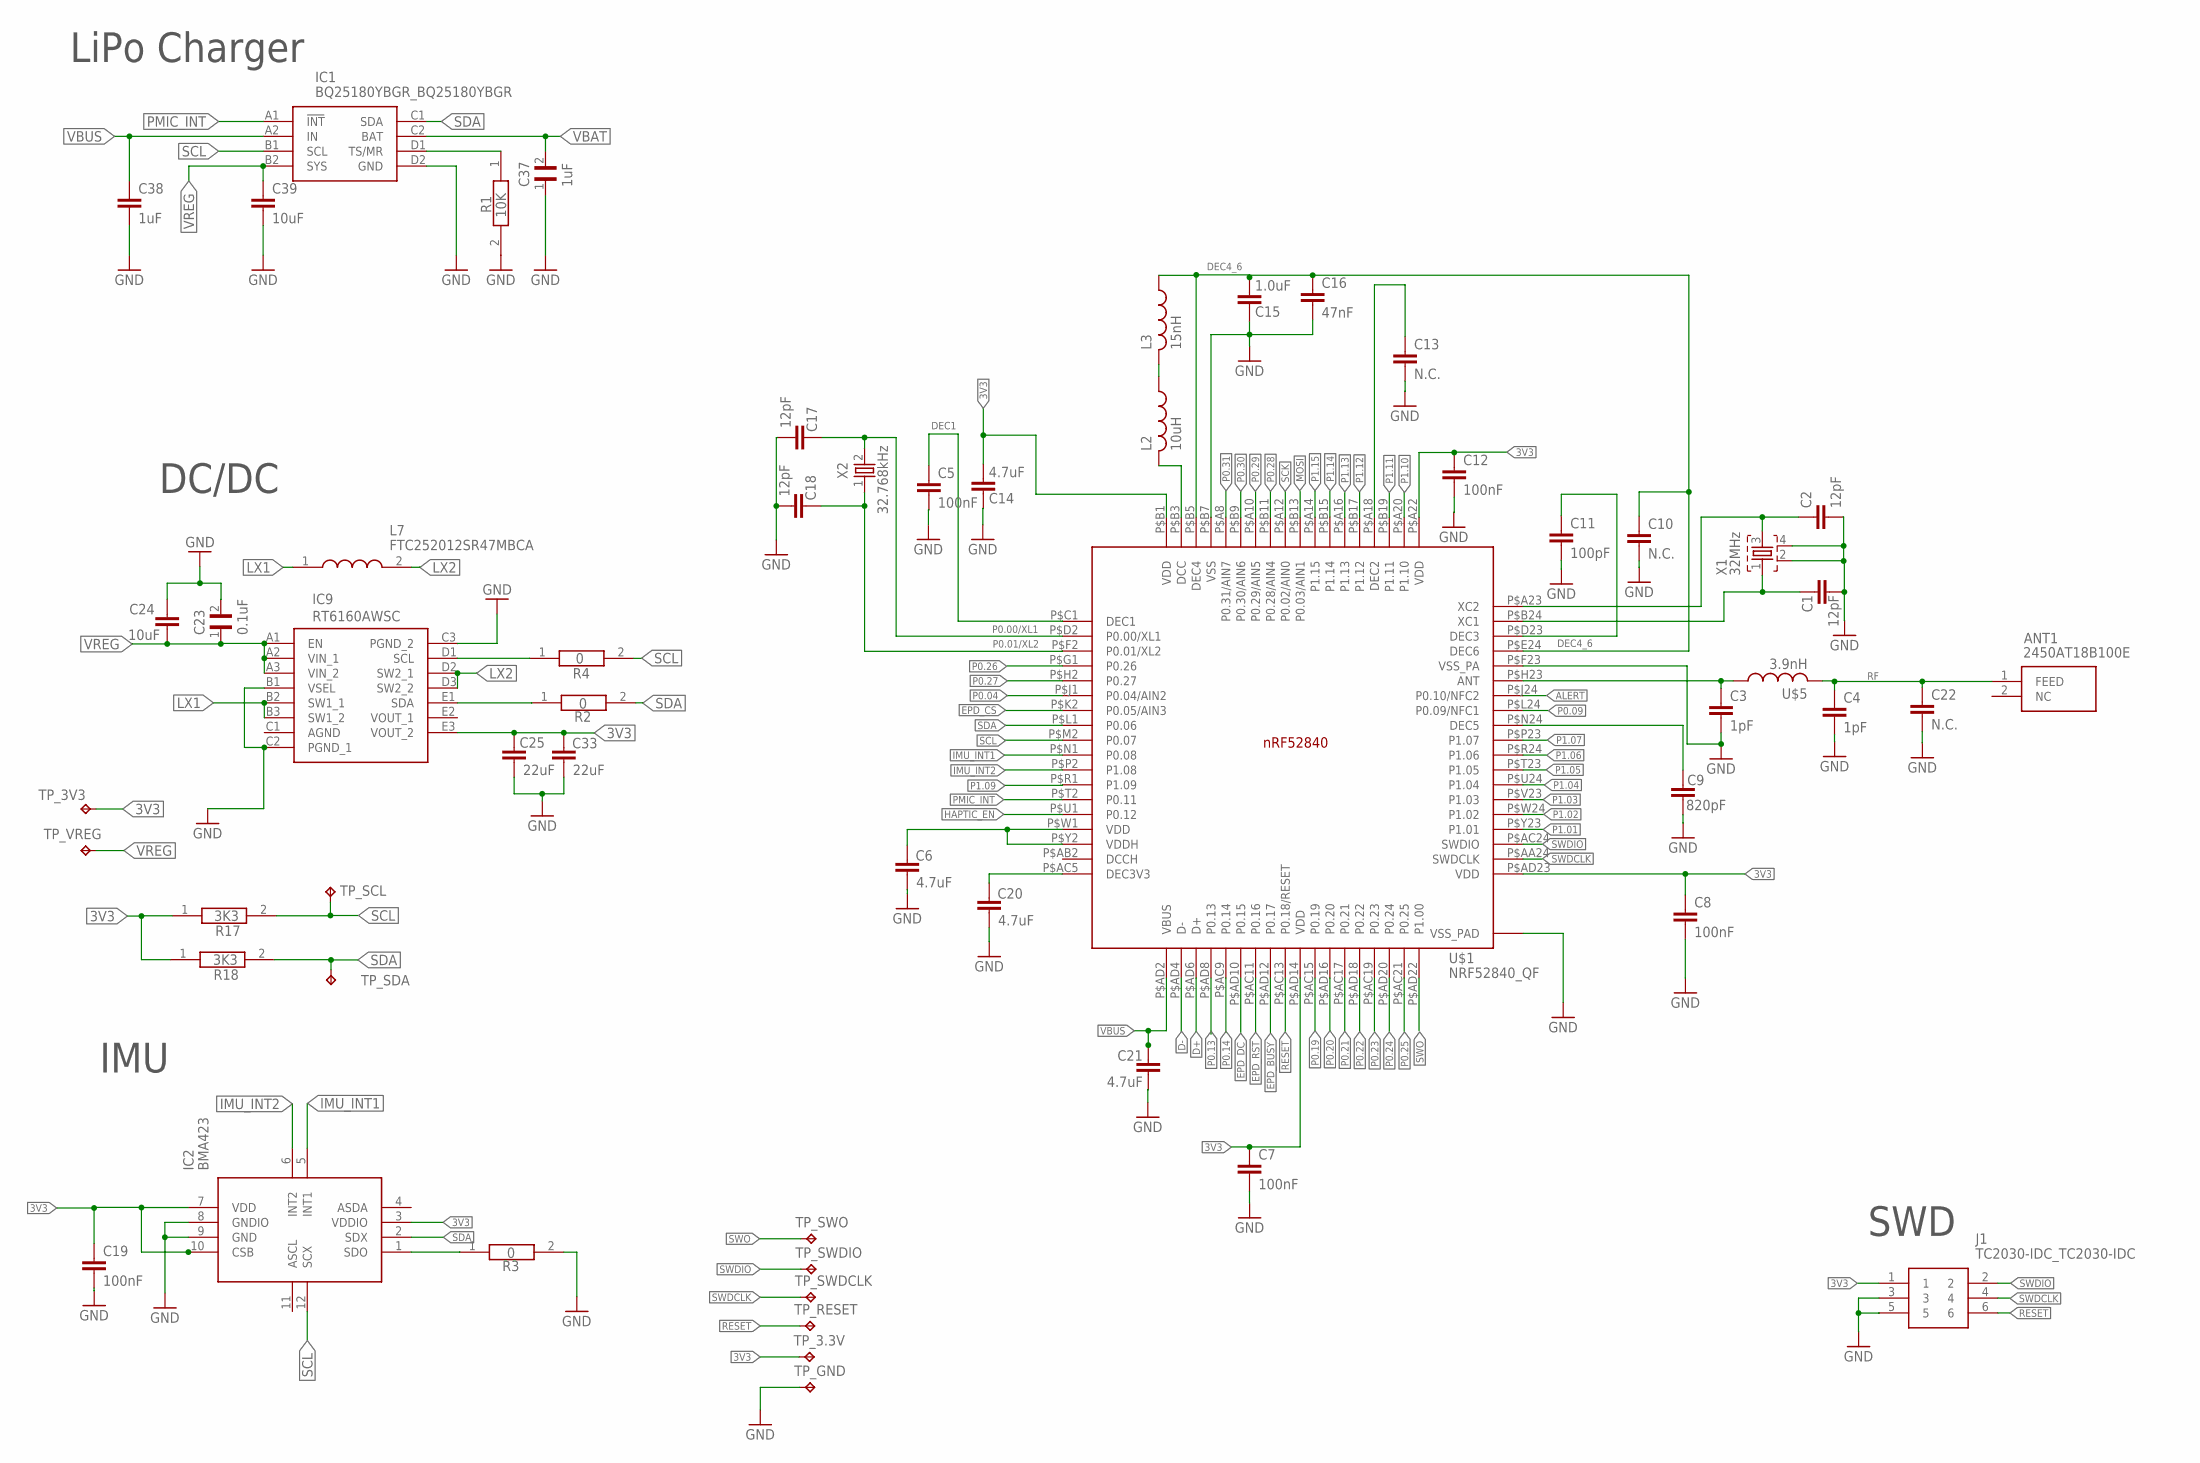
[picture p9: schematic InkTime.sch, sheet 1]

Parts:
ANT1: 2450AT18B100E; 2450AT18B100E_ANTC3216X140N
C1, C2, C17, C18: 12pF; NORDIC_NRF_3_RESC0201_N
C3, C4: 1pF; NORDIC_NRF_3_RESC0201_N
C5, C7, C8, C12, C19: 100nF; NORDIC_NRF_3_RESC0201_N
C6, C14, C20, C21: 4.7uF; NORDIC_NRF_3_RESC0402_N
C9: 820pF; NORDIC_NRF_3_RESC0201_N
C10, C13, C22: N.C.; NORDIC_NRF_3_RESC0201_N
C11: 100pF; NORDIC_NRF_3_RESC0201_N
C15: 1.0uF; NORDIC_NRF_3_RESC0402_N
C16: 47nF; NORDIC_NRF_3_RESC0201_N
C23: 0.1uF; GRM011R60J152KE01L_2_CAPC0201X13N
C24, C39: 10uF; NORDIC_NRF_3_RESC0402_N
C25, C33: 22uF; NORDIC_NRF_3_RESC0402_N
C37: 1uF; GRM011R60J152KE01L_2_CAPC0201X13N
C38: 1uF; NORDIC_NRF_3_RESC0402_N
IC1: BQ25180YBGR_BQ25180YBGR; BQ25180YBGR_BGA8C40P2X4_100X155X50
IC2: BMA423; BMA423_BMA423
IC9: RT6160AWSC; RT6160AWSC_BGA15C40P3X5_140X230X60
J1: TC2030-IDC_TC2030-IDC; TC2030-IDC_TC2030IDC
L2: 10uH; NORDIC_NRF_2_RESC0201_N
L3: 15nH; NORDIC_NRF_2_RESC0201_N
L7: FTC252012SR47MBCA; MLP2016SR47MT0S1_INDC2016X100N
R1: 10K; CPF0201D7K68C1_0201
R2, R3, R4: 0; CPF0201D7K68C1_0201
R17, R18: 3K3; CPF0201D7K68C1_0201
TP_3.3V, TP_3V3: HECTOR_WATCH_1_TPTP20R; HECTOR_WATCH_1_TP20R
TP_GND: HECTOR_WATCH_1_TPTP20R; HECTOR_WATCH_1_TP20R
TP_RESET: HECTOR_WATCH_1_TPTP20R; HECTOR_WATCH_1_TP20R
TP_SCL: HECTOR_WATCH_1_TPTP20R; HECTOR_WATCH_1_TP20R
TP_SDA: HECTOR_WATCH_1_TPTP20R; HECTOR_WATCH_1_TP20R
TP_SWDCLK: HECTOR_WATCH_1_TPTP20R; HECTOR_WATCH_1_TP20R
TP_SWDIO: HECTOR_WATCH_1_TPTP20R; HECTOR_WATCH_1_TP20R
TP_SWO: HECTOR_WATCH_1_TPTP20R; HECTOR_WATCH_1_TP20R
TP_VREG: HECTOR_WATCH_1_TPTP20R; HECTOR_WATCH_1_TP20R
U$1: NRF52840_QF; NORDIC_NRF_4_AQFN50P700X700X85_HS-74N
U$5: 3.9nH; NORDIC_NRF_2_RESC0201_N
X1: 32MHz; NORDIC_NRF_BT-XTAL_2016_N
X2: 32.768kHz; NORDIC_NRF_1_XTAL_3215_N

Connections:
3V3: C7.1, C8.1, C12.1, C14.2, C19.1, C25.1, C33.1, IC2.3 (VDDIO), IC9.E3 (VOUT_2), J1.1, R17.1, R18.1, TP_3.3V.TP, TP_3V3.TP, U$1.P$A22 (VDD), U$1.P$AD14 (VDD), U$1.P$AD23 (VDD), U$1.P$B1 (VDD); also elsewhere on the board
ALERT: U$1.P$J24 (P0.10/NFC2); also elsewhere on the board
D+: U$1.P$AD6 (D+); also elsewhere on the board
D-: U$1.P$AD4 (D-); also elsewhere on the board
DEC1: C5.1, U$1.P$C1 (DEC1)
DEC4_6: C10.1, C15.2, C16.1, L3.1, U$1.P$B5 (DEC4), U$1.P$E24 (DEC6)
EPD_BUSY: U$1.P$AD12 (P0.17); also elsewhere on the board
EPD_CS: U$1.P$K2 (P0.05/AIN3); also elsewhere on the board
EPD_DC: U$1.P$AD10 (P0.15); also elsewhere on the board
EPD_RST: U$1.P$AC11 (P0.16); also elsewhere on the board
GND: C1.2, C2.2, C3.2, C4.2, C5.2, C6.2, C7.2, C8.2, C9.2, C10.2, C11.2, C12.2, C13.2, C14.1, C15.1, C16.2, C17.2, C18.2, C19.2, C20.2, C21.2, C22.2, C23.2, C24.1, C25.2, C33.2, C37.1, C38.2, C39.2, IC1.D2 (GND), IC2.8 (GNDIO), IC2.9 (GND), IC9.B1 (VSEL), IC9.C2 (PGND_1), IC9.C3 (PGND_2), J1.3, J1.5, R1.2, R3.2, TP_GND.TP, U$1.P$74 (VSS_PAD), U$1.P$75 (VSS_PAD), U$1.P$76 (VSS_PAD), U$1.P$77 (VSS_PAD), U$1.P$78 (VSS_PAD), U$1.P$79 (VSS_PAD), U$1.P$80 (VSS_PAD), U$1.P$81 (VSS_PAD), U$1.P$82 (VSS_PAD), U$1.P$83 (VSS_PAD), U$1.P$84 (VSS_PAD), U$1.P$85 (VSS_PAD), U$1.P$86 (VSS_PAD), U$1.P$87 (VSS_PAD), U$1.P$88 (VSS_PAD), U$1.P$89 (VSS_PAD), U$1.P$90 (VSS_PAD), U$1.P$B7 (VSS), U$1.P$F23 (VSS_PA), X1.2, X1.4; also elsewhere on the board
HAPTIC_EN: U$1.P$U1 (P0.12); also elsewhere on the board
IMU_INT1: IC2.5 (INT1), U$1.P$N1 (P0.08)
IMU_INT2: IC2.6 (INT2), U$1.P$P2 (P1.08)
LX1: IC9.B2 (SW1_1), IC9.B3 (SW1_2), L7.1
LX2: IC9.D2 (SW2_1), IC9.D3 (SW2_2), L7.2
MOSI: U$1.P$B13 (P0.03/AIN1); also elsewhere on the board
unnamed: C20.1, U$1.P$AC5 (DEC3V3)
unnamed: IC9.D1 (SCL), R4.1
unnamed: IC9.E1 (SDA), R2.1
unnamed: IC1.D1 (TS/MR), R1.1
unnamed: C6.1, U$1.P$W1 (VDD)
unnamed: IC2.7 (VDD), IC2.10 (CSB)
unnamed: L2.2, U$1.P$B3 (DCC)
unnamed: L2.1, L3.2
unnamed: IC2.1 (SDO), R3.1
unnamed: C11.1, U$1.P$D23 (DEC3)
unnamed: C2.1, U$1.P$A23 (XC2), X1.3
unnamed: C13.1, U$1.P$A18 (DEC2)
unnamed: C1.1, U$1.P$B24 (XC1), X1.1
unnamed: C3.1, U$1.P$H23 (ANT), U$5.1
unnamed: C9.1, U$1.P$N24 (DEC5)
P0.00/XL1: C17.1, U$1.P$D2 (P0.00/XL1), X2.2
P0.01/XL2: C18.1, U$1.P$F2 (P0.01/XL2), X2.1
P0.04: U$1.P$J1 (P0.04/AIN2)
P0.09: U$1.P$L24 (P0.09/NFC1)
P0.13: U$1.P$AD8 (P0.13); also elsewhere on the board
P0.14: U$1.P$AC9 (P0.14); also elsewhere on the board
P0.19: U$1.P$AC15 (P0.19)
P0.20: U$1.P$AD16 (P0.20)
P0.21: U$1.P$AC17 (P0.21)
P0.22: U$1.P$AD18 (P0.22)
P0.23: U$1.P$AC19 (P0.23)
P0.24: U$1.P$AD20 (P0.24)
P0.25: U$1.P$AC21 (P0.25)
P0.26: U$1.P$G1 (P0.26)
P0.27: U$1.P$H2 (P0.27)
P0.28: U$1.P$B11 (P0.28/AIN4)
P0.29: U$1.P$A10 (P0.29/AIN5)
P0.30: U$1.P$B9 (P0.30/AIN6)
P0.31: U$1.P$A8 (P0.31/AIN7)
P1.01: U$1.P$Y23 (P1.01); also elsewhere on the board
P1.02: U$1.P$W24 (P1.02); also elsewhere on the board
P1.03: U$1.P$V23 (P1.03)
P1.04: U$1.P$U24 (P1.04)
P1.05: U$1.P$T23 (P1.05)
P1.06: U$1.P$R24 (P1.06)
P1.07: U$1.P$P23 (P1.07)
P1.09: U$1.P$R1 (P1.09)
P1.10: U$1.P$A20 (P1.10)
P1.11: U$1.P$B19 (P1.11)
P1.12: U$1.P$B17 (P1.12)
P1.13: U$1.P$A16 (P1.13)
P1.14: U$1.P$B15 (P1.14)
P1.15: U$1.P$A14 (P1.15)
PMIC_INT: IC1.A1 (!INT), U$1.P$T2 (P0.11)
RESET: J1.6, TP_RESET.TP, U$1.P$AC13 (P0.18/RESET)
RF: ANT1.1 (FEED), C4.1, C22.1, U$5.2
SCK: U$1.P$A12 (P0.02/AIN0); also elsewhere on the board
SCL: IC1.B1 (SCL), IC2.12 (SCX), R4.2, R17.2, TP_SCL.TP, U$1.P$M2 (P0.07); also elsewhere on the board
SDA: IC1.C1 (SDA), IC2.2 (SDX), R2.2, R18.2, TP_SDA.TP, U$1.P$L1 (P0.06); also elsewhere on the board
SWDCLK: J1.4, TP_SWDCLK.TP, U$1.P$AA24 (SWDCLK)
SWDIO: J1.2, TP_SWDIO.TP, U$1.P$AC24 (SWDIO)
SWO: TP_SWO.TP, U$1.P$AD22 (P1.00)
VBAT: C37.2, IC1.C2 (BAT); also elsewhere on the board
VBUS: C21.1, C38.1, IC1.A2 (IN), U$1.P$AD2 (VBUS); also elsewhere on the board
VREG: C23.1, C24.2, C39.1, IC1.B2 (SYS), IC9.A1 (EN), IC9.A2 (VIN_1), IC9.A3 (VIN_2), TP_VREG.TP

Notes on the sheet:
LiPo Charger
DC/DC
IMU
SWD

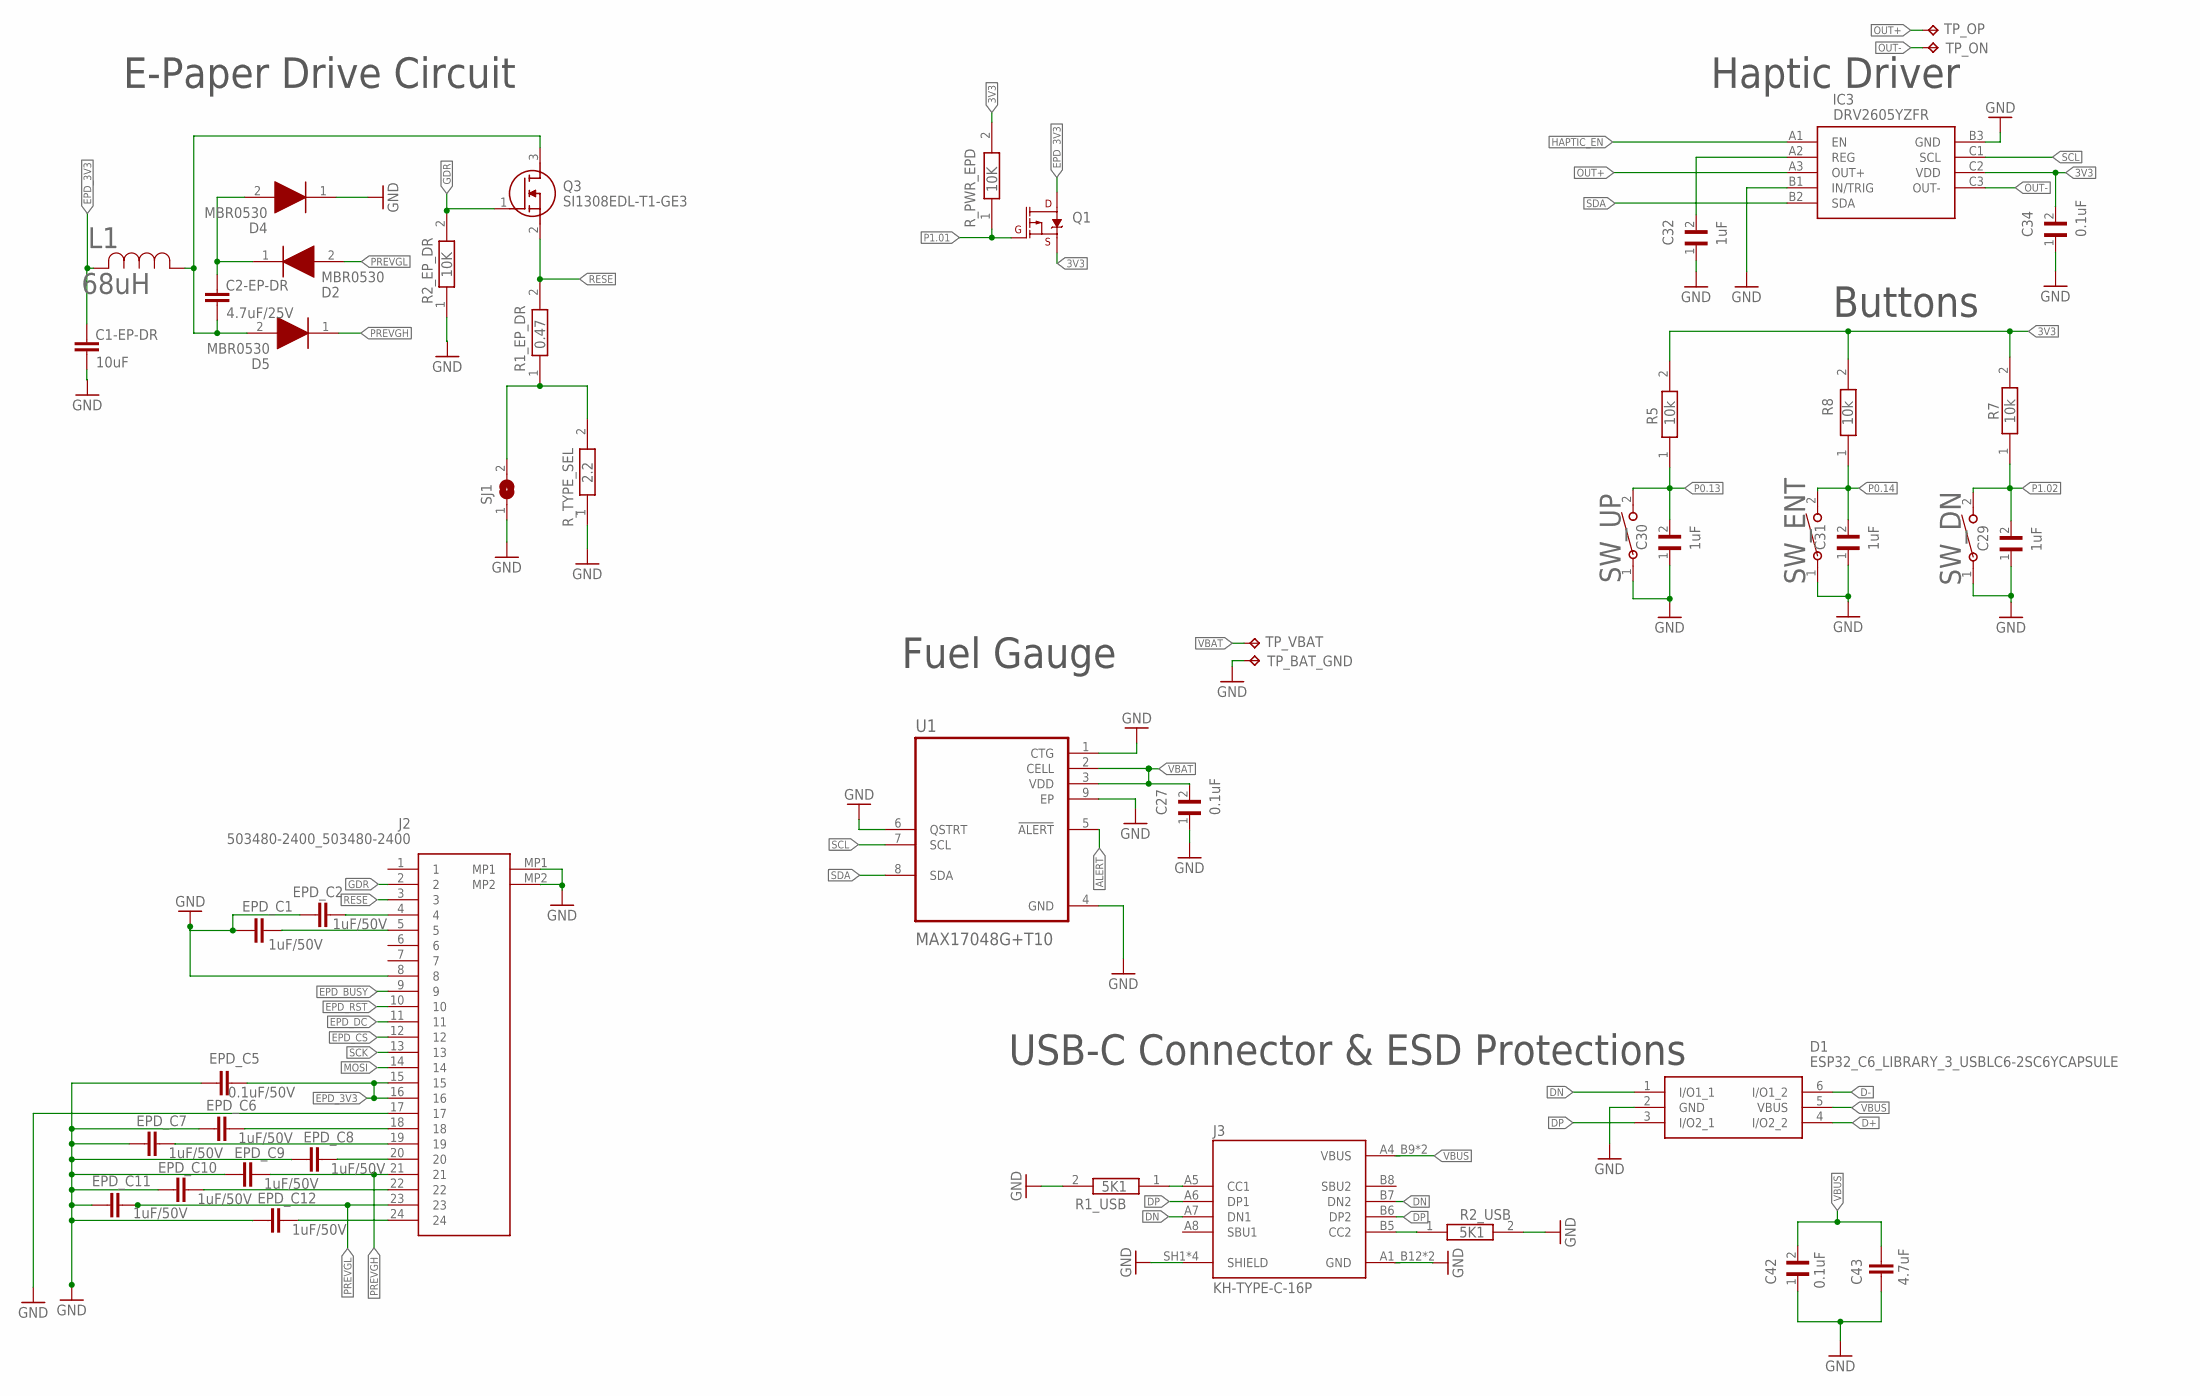
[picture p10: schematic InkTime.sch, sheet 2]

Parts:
C1-EP-DR: 10uF; NORDIC_NRF_3_RESC0402_N
C2-EP-DR: 4.7uF/25V; NORDIC_NRF_3_RESC0402_N
C27, C34, C42: 0.1uF; GRM011R60J152KE01L_2_CAPC0201X13N
C29, C30, C31, C32: 1uF; GRM011R60J152KE01L_2_CAPC0201X13N
C43: 4.7uF; NORDIC_NRF_3_RESC0402_N
D1: ESP32_C6_LIBRARY_3_USBLC6-2SC6YCAPSULE; ESP32_C6_LIBRARY_3_SOT95P280X145-6N
D2, D4, D5: MBR0530; ESP32_C6_LIBRARY_5_SOD3716X135N
EPD_C1, EPD_C2, EPD_C6, EPD_C7, EPD_C8, EPD_C9, EPD_C10, EPD_C11, EPD_C12: 1uF/50V; NORDIC_NRF_3_RESC0402_N
EPD_C5: 0.1uF/50V; NORDIC_NRF_3_RESC0402_N
IC3: DRV2605YZFR; DRV2605YZFR_BGA9C50P3X3_144X144X62
J2: 503480-2400_503480-2400; 503480-2400_5034802400
J3: KH-TYPE-C-16P; KH-TYPE-C-16P_KINGHELM_KH-TYPE-C-16P
L1: 68uH; ESP32_C6_LIBRARY_2_IND_4828-WE-TPC_WRE
Q1: ESP32_C6_LIBRARY_4_ESP32_WROVER_SPARKFUN-DISCRETE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; ESP32_C6_LIBRARY_4_ESP32_C6_LIBRARY_4_ESP32_C6_LIBRARY_4_ES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
Q3: SI1308EDL-T1-GE3; ESP32_C6_LIBRARY_6_SOT65P210X110-3N
R1_EP_DR: 0.47; CPF0201D7K68C1_0201
R1_USB, R2_USB: 5K1; CPF0201D7K68C1_0201
R2_EP_DR: 10K; CPF0201D7K68C1_0201
R5, R7, R8: 10k; CPF0201D7K68C1_0201
R_PWR_EPD: 10K; CPF0201D7K68C1_0201
R_TYPE_SEL: 2.2; CPF0201D7K68C1_0201
SJ1: ESP32_C6_LIBRARY_7_JUMPER_SJ
SW_DN: 2025-10-22_07-23-44_LIBRARY_EVP-AKE31A; 2025-10-22_07-23-44_LIBRARY_SW_EVP-AKE31A_PAN
SW_ENT: 2025-10-22_07-23-44_LIBRARY_EVP-AKE31A; 2025-10-22_07-23-44_LIBRARY_SW_EVP-AKE31A_PAN
SW_UP: 2025-10-22_07-23-44_LIBRARY_EVP-AKE31A; 2025-10-22_07-23-44_LIBRARY_SW_EVP-AKE31A_PAN
TP_BAT_GND: HECTOR_WATCH_1_TPTP20R; HECTOR_WATCH_1_TP20R
TP_ON: HECTOR_WATCH_1_TPTP20R; HECTOR_WATCH_1_TP20R
TP_OP: HECTOR_WATCH_1_TPTP20R; HECTOR_WATCH_1_TP20R
TP_VBAT: HECTOR_WATCH_1_TPTP20R; HECTOR_WATCH_1_TP20R
U1: MAX17048G+T10; ESP32_C6_LIBRARY_SON50P200X200X80-9N

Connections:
3V3: C34.2, IC3.C2 (VDD), Q1.2 (S), R5.2, R7.2, R8.2, R_PWR_EPD.2; also elsewhere on the board
ALERT: U1.5 (!ALERT); also elsewhere on the board
D+: D1.4 (I/O2_2); also elsewhere on the board
D-: D1.6 (I/O1_2); also elsewhere on the board
DN: D1.1 (I/O1_1), J3.A7 (DN1), J3.B7 (DN2)
DP: D1.3 (I/O2_1), J3.A6 (DP1), J3.B6 (DP2)
EPD_3V3: C1-EP-DR.1, EPD_C5.2, J2.15, J2.16, L1.2, Q1.3 (D)
EPD_BUSY: J2.9; also elsewhere on the board
EPD_CS: J2.12; also elsewhere on the board
EPD_DC: J2.11; also elsewhere on the board
EPD_RST: J2.10; also elsewhere on the board
GDR: J2.2, Q3.1 (G), R2_EP_DR.2
GND: C1-EP-DR.2, C27.1, C29.1, C30.1, C31.1, C32.1, C34.1, C42.1, C43.1, D1.2 (GND), D4.1 (K), EPD_C1.1, EPD_C2.1, EPD_C5.1, EPD_C6.1, EPD_C7.1, EPD_C8.1, EPD_C9.1, EPD_C10.1, EPD_C11.1, EPD_C12.1, IC3.B1 (IN/TRIG), IC3.B3 (GND), J2.8, J2.17, J2.MP1, J2.MP2, J3.A1_B12 (GND), J3.A12_B1 (GND), J3.SH1 (SHIELD), J3.SH2 (SHIELD), J3.SH3 (SHIELD), J3.SH4 (SHIELD), R1_USB.2, R2_EP_DR.1, R2_USB.2, R_TYPE_SEL.1, SJ1.1, SW_DN.1, SW_ENT.1, SW_UP.1, TP_BAT_GND.TP, U1.1 (CTG), U1.4 (GND), U1.6 (QSTRT), U1.9 (EP); also elsewhere on the board
HAPTIC_EN: IC3.A1 (EN); also elsewhere on the board
MOSI: J2.14; also elsewhere on the board
unnamed: C32.2, IC3.A2 (REG)
unnamed: C2-EP-DR.2, D5.2 (A), L1.1, Q3.3 (D)
unnamed: C2-EP-DR.1, D2.1 (K), D4.2 (A)
unnamed: EPD_C2.2, J2.4
unnamed: EPD_C1.2, J2.5
unnamed: R1_EP_DR.1, R_TYPE_SEL.2, SJ1.2
unnamed: J3.A5 (CC1), R1_USB.1
unnamed: J3.B5 (CC2), R2_USB.1
unnamed: EPD_C10.2, J2.22
unnamed: EPD_C6.2, J2.18
unnamed: EPD_C7.2, J2.19
unnamed: EPD_C8.2, J2.20
unnamed: EPD_C12.2, J2.24
OUT+: IC3.A3 (OUT+), TP_OP.TP
OUT-: IC3.C3 (OUT-), TP_ON.TP
P0.13: C30.2, R5.1, SW_UP.2; also elsewhere on the board
P0.14: C31.2, R8.1, SW_ENT.2; also elsewhere on the board
P1.01: Q1.1 (G), R_PWR_EPD.1; also elsewhere on the board
P1.02: C29.2, R7.1, SW_DN.2; also elsewhere on the board
PREVGH: D5.1 (K), EPD_C9.2, J2.21
PREVGL: D2.2 (A), EPD_C11.2, J2.23
RESE: J2.3, Q3.2 (S), R1_EP_DR.2
SCK: J2.13; also elsewhere on the board
SCL: IC3.C1 (SCL), U1.7 (SCL); also elsewhere on the board
SDA: IC3.B2 (SDA), U1.8 (SDA); also elsewhere on the board
VBAT: C27.2, TP_VBAT.TP, U1.2 (CELL), U1.3 (VDD); also elsewhere on the board
VBUS: C42.2, C43.2, D1.5 (VBUS), J3.A4_B9 (VBUS), J3.A9_B4 (VBUS); also elsewhere on the board

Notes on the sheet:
E-Paper Drive Circuit
Fuel Gauge
Haptic Driver
Buttons
USB-C Connector & ESD Protections

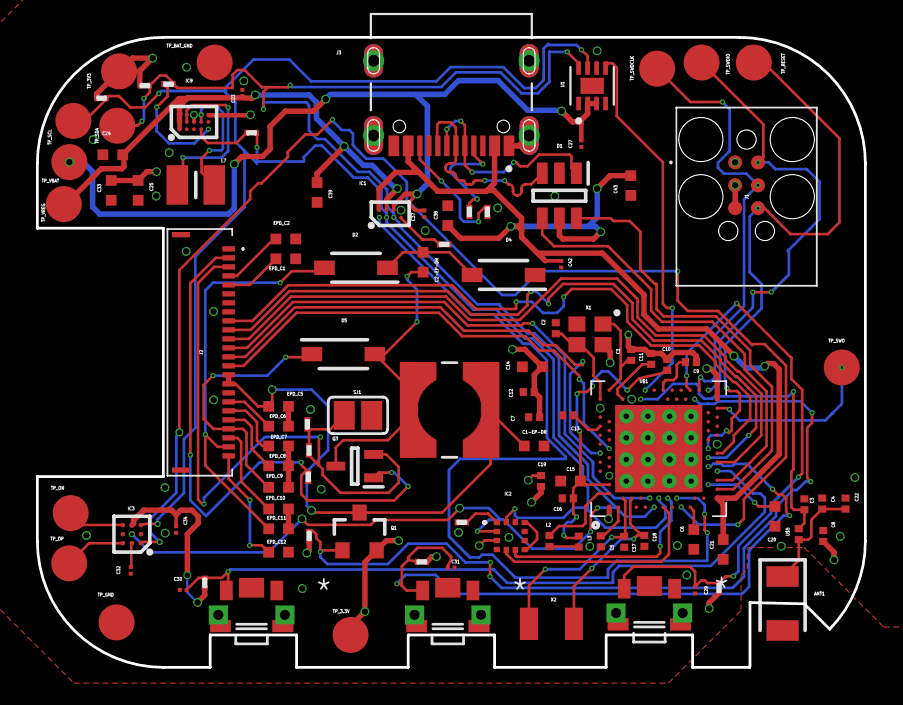
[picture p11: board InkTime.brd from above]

Board: 4 copper layers, 46.0 x 35.0 mm, 105 parts (0 on the bottom side), 72 nets.

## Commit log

2026-04-09 added: inktime watch
    [InkTime.brd, InkTime.sch]
2026-04-21 fixed: issue 1, 2 and 3
    [InkTime.brd, InkTime.sch]
2026-04-21 added: schematic in pdf form

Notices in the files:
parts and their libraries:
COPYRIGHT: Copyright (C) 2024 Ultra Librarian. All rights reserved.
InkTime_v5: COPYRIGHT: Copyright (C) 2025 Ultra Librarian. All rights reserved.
